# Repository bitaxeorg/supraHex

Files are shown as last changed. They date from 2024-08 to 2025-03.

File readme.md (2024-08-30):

> Closed Source is Antithetical to Bitcoin

# Presenting: The supraHex
supraHex is a follow on to the [bitaxe](https://github.com/skot/bitaxe) that incorporates six BM1368 ASICs from the Antminer S21

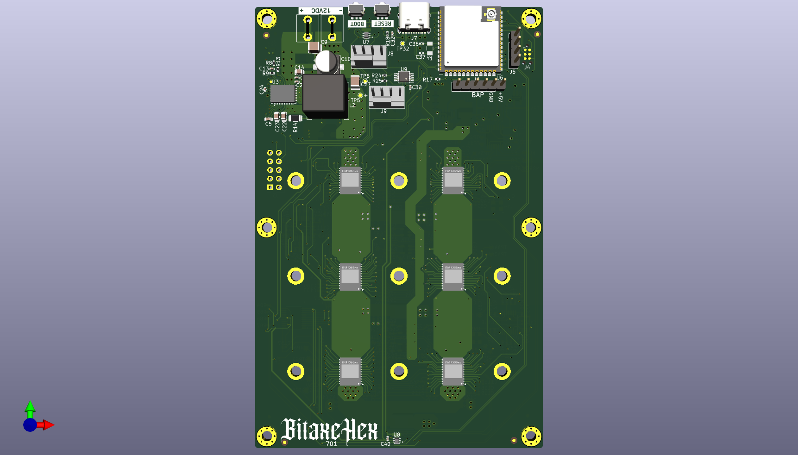
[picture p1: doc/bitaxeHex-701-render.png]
supraHex render


## Goals
- **Standalone**: can mine directly to your pool over WiFi. No External computer needed.
- **Embedded**: low cost, low maintenance, high availability, high reliability, low power.
- **ASIC**: based on the very efficient BM1368 from Bitmain.
- **Versatile**: solo/pool mining, autotune power/heat/efficiency.
- **Open Source**: All design files are provided.

## Features
- **ESP32-S3-WROOM-1** wifi microcontroller on board
- **TI TPS546D24ARVFR** buck regulator steps down the 12V input to power the chain of BM1368
- **TMP1075** measures inlet and outlet PCB temperature.
- **Microchip EMC2302** Controls dual fans
- Header for optional status LCD
- BAP (Bitaxe Accesory Port)
- ASIC Chip temperature directly from the ASIC's

## BM1368
- The BM1368 is a undocumented SHA256 mining ASIC from Bitmain. It's mostly used in the Antminer S21
- Bitmain claims the BM1368 has 17.5 W/TH efficiency
- The BM1368 is available (new) for around $20~29 each.

## Current Status
- v701 hardware is working! Hash rate is fluctuating between 4 TH/s and 4.2 TH/s.
- Power draw is around 75W @12V.
- ESP32 miner firmware will configure the power supply to run at the proper voltage.
- This is an _advanced_ build! If you don't have experience building boards, you should probably go build a single ASIC bitaxe first to get the technique down.

## Revision List
- V701 is the current working version of this board.  If you want to build this, pull down this git tag.

## Hardware
- [BM1368 from NBTC](https://www.nbtcminer.com/shop/miner-parts/miner-chip/new-bm1368-bm1368pb-for-antminer-s21-t21-hdyro/). The `PB`Variant seems to work fine.
- [Heatsink](https://www.aliexpress.us/item/3256805608902122.html) 90mm long variant. This will need to have threaded M3 mounting holes added. See the KiCad board file for the pattern
- [Fans](https://www.amazon.com/Noctua-NF-A8-PWM-Premium-Quiet/dp/B00NEMG62M) At least one 80x80mm 12V 4-pin fan. Like the Noctua NF-A8 PWM. Possibly two.
- [Enclosure](https://www.aliexpress.us/item/3256806064761702.html) (several sellers) 130mm long variant. The supraHex needs to be run inside an enclosure to force air through the heatsink and effectively cool the BM1368s
- All of the parts on the board are listed in the KiCad BOM

## Software
- [ESP-Miner-Multichip](https://github.com/bitaxeorg/esp-miner-multichip) is still being updated to support multiple ASICs

## Power Supply Requirements
- supraHex takes 12V DC input via screw terminals. Power supply should be capable of 100W
  - This [120W Brick](https://www.amazon.com/gp/product/B07PWZQ33N) technically works, but gets a little warmer than it should. You'll need to change the end.
  - 12V 15A 110V AliExpress [Bare PSU](https://www.aliexpress.us/item/3256805439916551.html)

## Building
- Check out [building.md](building.md) for PCB ordering tips
- Check out [assembly.md](assembly.md) for assembly tips

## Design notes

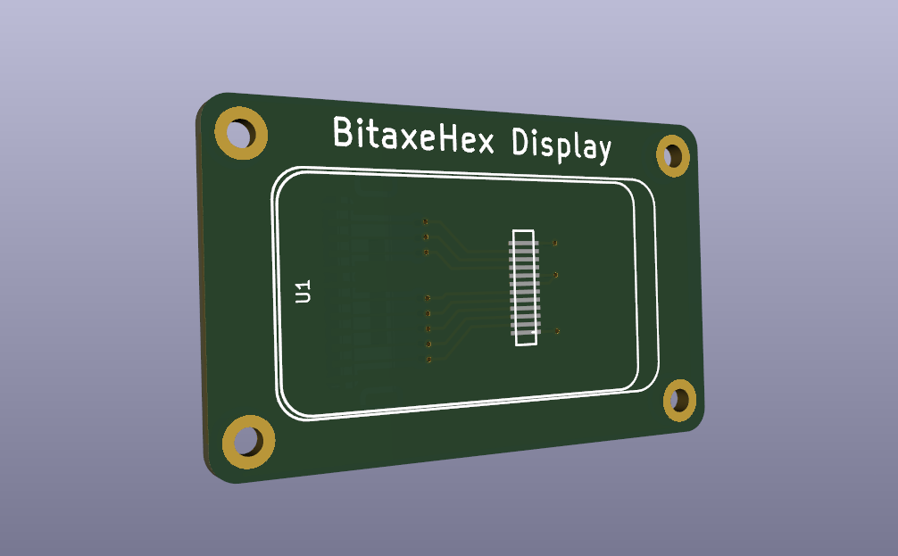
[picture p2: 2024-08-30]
hex-display/doc/display-board-render-front.png

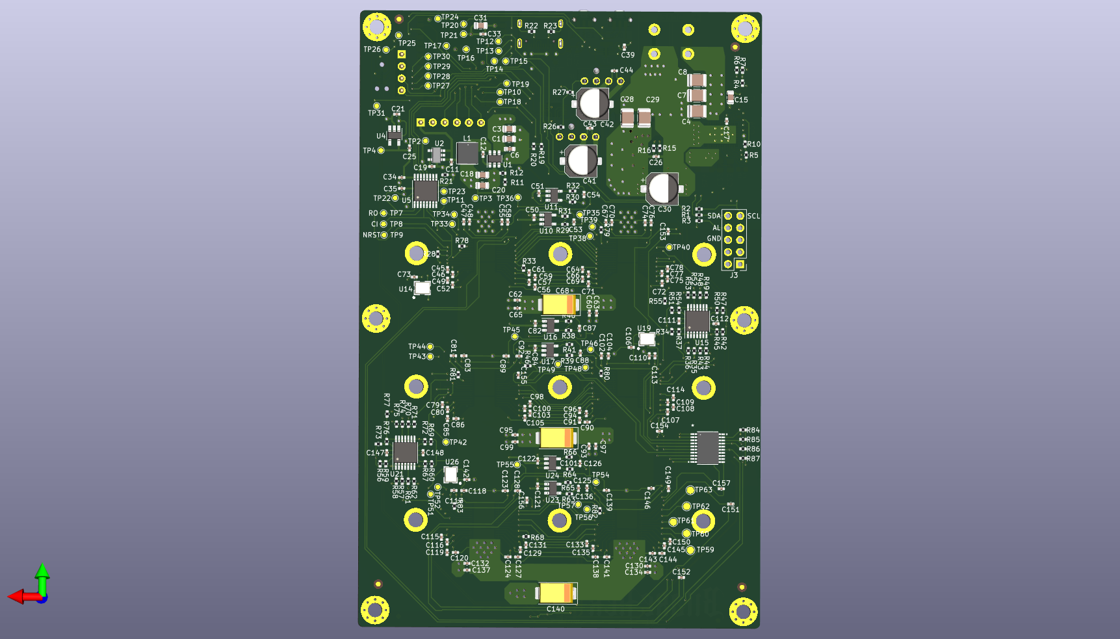
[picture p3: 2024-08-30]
doc/bitaxeHex-701-render-back.png

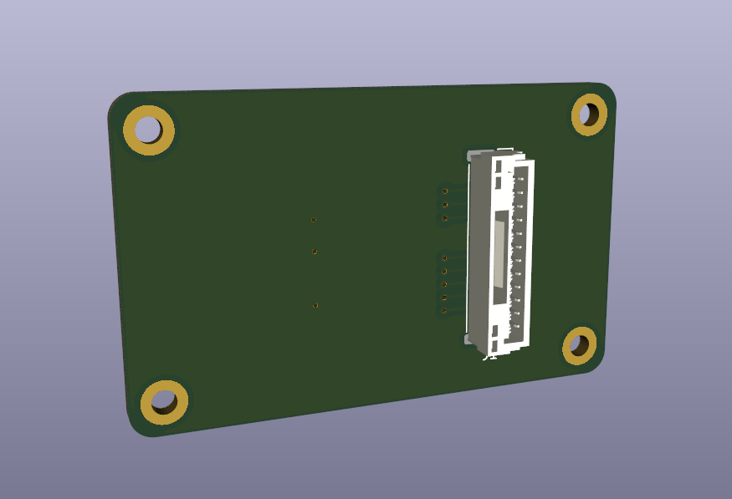
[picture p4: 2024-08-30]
hex-display/doc/display-board-render-back.png

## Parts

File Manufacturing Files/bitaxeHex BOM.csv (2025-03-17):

Reference | Value | Footprint | Qty | DK | PARTNO
C1, C3, C18, C20, C31 | 10uF | Capacitor_SMD:C_0805_2012Metric | 5 | 490-18664-1-ND | GRM21BR61H106ME43L
C2 | 4.7nF | Capacitor_SMD:C_0402_1005Metric | 1 | 490-1309-1-ND | GRM155R71E472KA01D
C4, C7, C8, C9 | 22uF | Capacitor_SMD:C_1210_3225Metric | 4 | 490-3889-1-ND | GRM32ER61E226KE15L
C5 | 1uF | Capacitor_SMD:C_0603_1608Metric | 1 | 490-1550-1-ND | GRM188R60J105KA01D
C6 | 0.1uF | Capacitor_SMD:C_0603_1608Metric | 1 | 478-KGM15BR71H104KTCT-ND | KGM15BR71H104KT
C10, C30 | 180uF | Capacitor_SMD:CP_Elec_6.3x5.9 | 2 | P16479CT-ND | 16SVPF180M
C11, C19, C21, C25, C32, C45, C46, C47, C48, C49, C52, C53, C54, C55, C56, C57, C58, C59, C61, C63, C64, C65, C66, C67, C69, C70, C71, C72, C74, C75, C76, C77, C78, C79, C80, C81, C83, C85, C86, C87, C88, C89, C90, C91, C92, C94, C96, C97, C98, C99, C100, C102, C103, C104, C105, C107, C108, C109, C110, C112, C113, C114, C115, C116, C117, C118, C119, C120, C123, C124, C125, C126, C127, C128, C129, C131, C133, C134, C135, C136, C137, C138, C139, C141, C143, C144, C145, C146, C148, C149, C150 | 1uF | Capacitor_SMD:C_0402_1005Metric | 91 | 587-5514-1-ND | EMK105BJ105MV-F
C12, C33, C50, C51, C60, C62, C73, C82, C84, C93, C95, C106, C111, C121, C122, C130, C132, C142, C147, C151 | 0.1uF | Capacitor_SMD:C_0402_1005Metric | 20 | 478-KGM05AR71C104KHCT-ND | KGM05AR71C104KH
C13 | 100nF | Capacitor_SMD:C_0402_1005Metric | 1 | 490-6321-1-ND | GRM155R71A104KA01D
C14, C15 | 1uF | Capacitor_SMD:C_0805_2012Metric | 2 | 587-1291-1-ND | TMK212BJ105KG-T
C16, C26 | 2.2nF | Capacitor_SMD:C_0402_1005Metric | 2 | 490-8257-1-ND | GRM155R61H222KA01D
C17 | 4.7uF | Capacitor_SMD:C_0402_1005Metric | 1 | 490-14306-1-ND | GRM155R61A475MEAAD
C22 | 1nF | Capacitor_SMD:C_0805_2012Metric | 1 | 311-1127-1-ND | CC0805KRX7R9BB102
C23 | 100nF | Capacitor_SMD:C_0805_2012Metric | 1 | 478-KGM21NR71E104KTCT-ND | KGM21NR71E104KT
C24 | 100pF | Capacitor_SMD:C_0402_1005Metric | 1 | 732-7431-1-ND | 885012005013
C27, C28, C29 | 47uF | Capacitor_SMD:C_1210_3225Metric | 3 | 490-6539-1-ND | GRM32ER61C476KE15L
C34, C35, C38, C39, C40, C43, C44 | 311-3342-1-ND | Capacitor_SMD:C_0402_1005Metric | 7 | 478-KGM05AR71C104KHCT-ND | KGM05AR71C104KH
C41, C42 | 220uF | Capacitor_SMD:CP_Elec_6.3x7.7 | 2 | 732-8422-1-ND | 865080345012
C68, C101, C140 | 330uF | Capacitor_Tantalum_SMD:CP_EIA-7343-31_Kemet-D_Pad2.25x2.55mm_HandSolder | 3 | 718-1028-1-ND | 293D337X9010E2TE3
C152, C153, C154, C155, C156, C157 | 2.2nF | Capacitor_SMD:C_0402_1005Metric | 6 | 311-1037-2-ND | CC0402KRX7R9BB222
D1 | 824045812 | bitaxe:824045812 | 1 | 732-824045812CT-ND | 824045812
J1, J2 | Screw Terminal | bitaxe:7771-screw-terminal | 2 | 36-7771-ND | 36-7771
J3 | Conn_02x05_Odd_Even | Connector_PinHeader_2.54mm:PinHeader_2x05_P2.54mm_Vertical | 1
J6 | Conn_01x06 | Connector_PinHeader_2.54mm:PinHeader_1x06_P2.54mm_Vertical | 1
J7 | USB_C_Receptacle_USB2.0 | Connector_USB:USB_C_Receptacle_GCT_USB4105-xx-A_16P_TopMnt_Horizontal | 1 | 2073-USB4105-GF-ACT-ND | USB4105-GF-A
J8, J9 | Conn_01x04 | bitaxe:470531000 | 2 | WM4330-ND | 0470531000
L1 | 8.2 uH | bitaxe:74438357082 | 1 | 732-11745-1-ND | 78438357082
L2 | 680nH | Inductor_SMD:L_Coilcraft_XAL1010-XXX | 1 | 2457-XAL1010-681MED-ND | XAL1010-681MED
R1, R2, R3 | 0R | Resistor_SMD:R_0402_1005Metric | 3 | 311-0.0JRCT-ND | RC0402JR-070RL
R4, R5 | 17.8K | Resistor_SMD:R_0402_1005Metric | 2 | RMCF0402FT17K8CT-ND | RMCF0402FT17K8
R6 | 10k | Resistor_SMD:R_0402_1005Metric | 1 | RMCF0402FT10K0CT-ND | RMCF0402FT10K0
R7 | 31.6K | Resistor_SMD:R_0402_1005Metric | 1 | YAG3115CT-ND | RC0402FR-0731K6L
R8 | 12.7K | Resistor_SMD:R_0402_1005Metric | 1 | YAG2964CT-ND | RC0402FR-0712K7L
R9, R16 | 1.37K | Resistor_SMD:R_0402_1005Metric | 2 | YAG3035CT-ND | RC0402FR-071K37L
R10 | 26.1K | Resistor_SMD:R_0402_1005Metric | 1 | 311-26.1KLRCT-ND | RC0402FR-0726K1L
R11, R29, R30, R31, R38, R39, R41, R63, R64, R65 | 115k | Resistor_SMD:R_0402_1005Metric | 10 | YAG2956CT-ND | RC0402FR-07115KL
R12, R20 | 22.1k | Resistor_SMD:R_0402_1005Metric | 2 | 311-22.1KLRCT-ND | RC0402FR-0722K1L
R13 | 10R | Resistor_SMD:R_0402_1005Metric | 1 | 311-10.0LRCT-ND | RC0402FR-0710RL
R14 | 1R | Resistor_SMD:R_1206_3216Metric | 1 | CSR1206FT1R00CT-ND | CSR1206FT1R00
R15 | 49.9R | Resistor_SMD:R_0402_1005Metric | 1 | 311-49.9LRCT-ND | RC0402FR-0749R9L
R17, R18, R26, R27, R28, R35, R36, R43, R44, R48, R49, R52, R53, R57, R58, R61, R62, R70, R71, R74, R75 | 10k | Resistor_SMD:R_0402_1005Metric | 21 | 311-10KJRCT-ND | RC0402JR-0710KL
R19 | 7.87k | Resistor_SMD:R_0402_1005Metric | 1 | 311-7.87KLRCT-ND | RC0402FR-077K87L
R21 | 20k | Resistor_SMD:R_0402_1005Metric | 1 | 311-20.0KLRCT-ND | RC0402FR-0720KL
R22, R23 | 5.1k | Resistor_SMD:R_0402_1005Metric | 2 | 13-RC0402FR-135K1LCT-ND | RC0402FR-135K1L
R24, R25 | 5.6k | Resistor_SMD:R_0402_1005Metric | 2 | 13-RC0402FR-135K6LCT-ND | RC0402FR-135K6L
R32, R40, R66 | 402k | Resistor_SMD:R_0402_1005Metric | 3 | YAG3151CT-ND | RC0402FR-07402KL
R33, R46, R68 | 2k | Resistor_SMD:R_0402_1005Metric | 3 | YAG2303CT-ND | RT0402BRD072KL
R34, R37, R42, R45, R47, R50, R51, R54, R55, R56, R59, R60, R67, R69, R72, R73, R76, R77, R78, R79, R80, R81, R82, R83 | 1k | Resistor_SMD:R_0402_1005Metric | 24 | 311-1.00KLRCT-ND | RC0402FR-071KL
R84, R85, R86, R87 | 4.7k | Resistor_SMD:R_0402_1005Metric | 4 | YAG1446TR-ND | RT0402BRD074K7L
SW1, SW2 | SWITCH-SPST | bitaxe:TL3340-switch | 2 | EG4627CT-ND | TL3340AF160QG
U1 | LMR54410 | Package_TO_SOT_SMD:SOT-23-6 | 1 | 296-LMR54410DBVRCT-ND | LMR54410FDBVR
U2 | RT9080-33GJ5 | bitaxe:RT9080-33GJ5 | 1 | 1028-1509-1-ND | RT9080-33GJ5
U3 | TPS546D24ARVFR | bitaxe:LQFN40-CLIP | 1 | 296-TPS546D24ARVFRCT-ND | TPS546D24ARVFR
U4 | MIC5504-MS | Package_TO_SOT_SMD:SOT-23-5_HandSoldering | 1 | 576-4879-1-ND | MIC5504-1.8YM5-TR
U5 | SN74AVC4T774 | Package_SO:TSSOP-16_4.4x5mm_P0.65mm | 1 | 296-24739-1-ND | SN74AVC4T774PWR
U6 | ESP32-S3-WROOM-1 | bitaxe:ESP32-S3-WROOM-1U | 1 | 1965-ESP32-S3-WROOM-1U-N16R8CT-ND | ESP32-S3-WROOM-1U-N16R8
U7, U8 | TMP1075 | bitaxe:SOT5X3-6_DRL_TEX | 2 | 296-TMP1075NDRLRCT-ND | TMP1075NDRLR
U9 | EMC2302 | Package_SO:MSOP-10_3x3mm_P0.5mm | 1 | EMC2302-2-AIZL-CT-ND | EMC2302-2-AIZL-TR
U10, U11, U16, U17, U23, U24 | AP7331 | Package_TO_SOT_SMD:TSOT-23-5 | 6 | AP7331-WG-7DICT-ND | AP7331-WG-7
U12, U25, U27, U28 | BM1368_mode1 | bitaxe:BM1368 | 4
U13, U18 | BM1368_mode0 | bitaxe:BM1368 | 2
U14, U19, U26 | 25MHz | bitaxe:O 25,0-JO32-B-1V3-1-T1-LF | 3 | 1908-O250-JO32-B-1V3-1-T1-LFCT-ND | O 25,0-JO32-B-1V3-1-T1-LF
U15, U21 | TLV3544 | Package_SO:TSSOP-14_4.4x5mm_P0.65mm | 2 | 296-45352-1-ND | TLV3544IPWR
U20 | ~ | bitaxe:MAX6689UP9A+ | 1 | MAX6689UP9A+-ND | MAX6689UP9A+

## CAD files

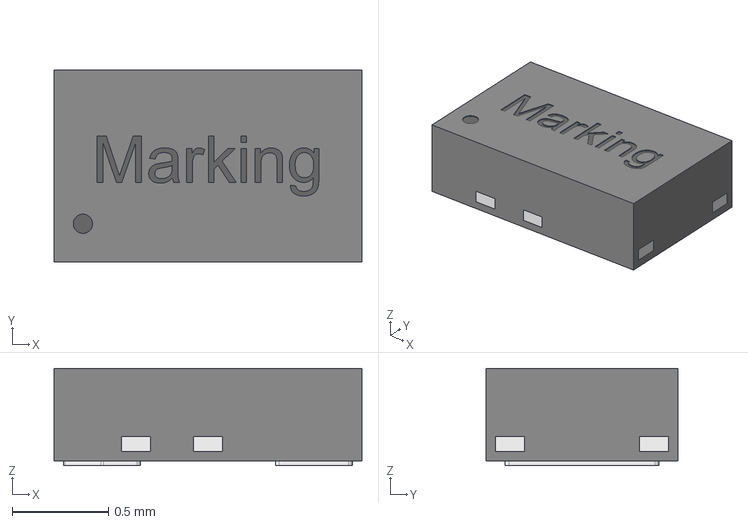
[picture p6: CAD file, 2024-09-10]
3d/Download_STP_WE-TVS-DFN1610-2L_rev1.stp
1.60 x 1.00 x 0.505 mm
pins x 7
housing

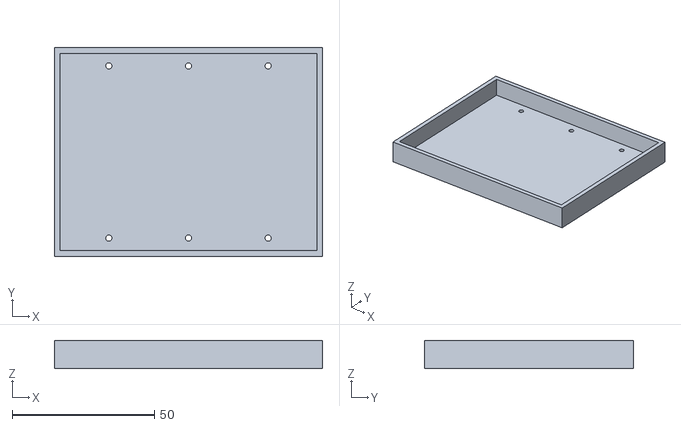
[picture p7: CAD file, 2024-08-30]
3d/heatsink-drill-guide.stl
94.2 x 73.3 x 10.0

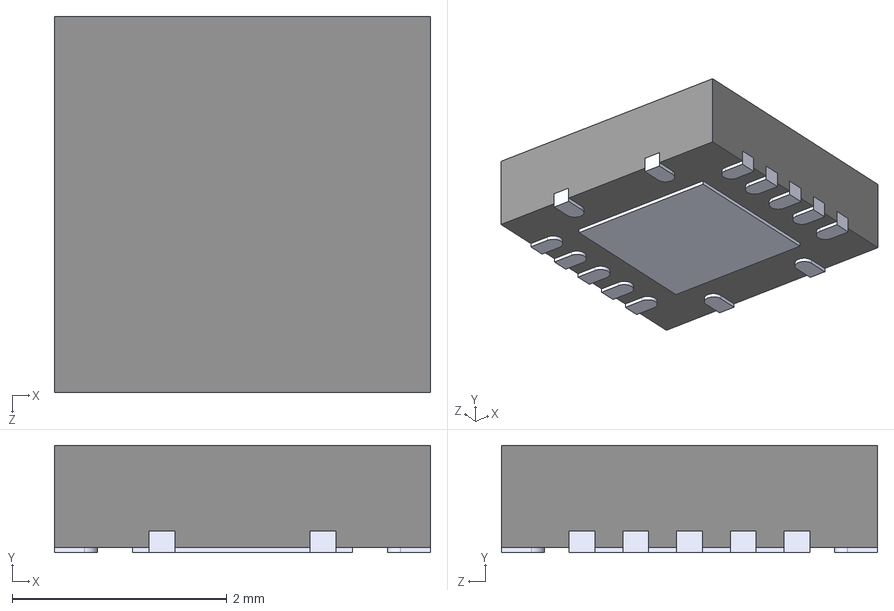
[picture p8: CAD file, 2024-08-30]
3d/TXB0104RGYR.STEP
3.50 x 1.00 x 3.50 mm

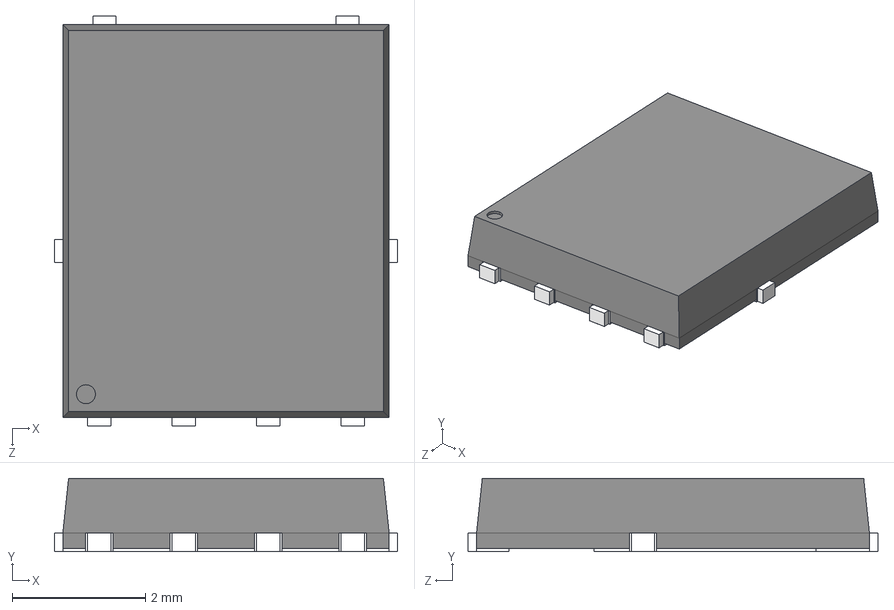
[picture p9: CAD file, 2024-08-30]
3d/NTMFS5C673NLT1G.STEP
5.15 x 1.10 x 6.15 mm

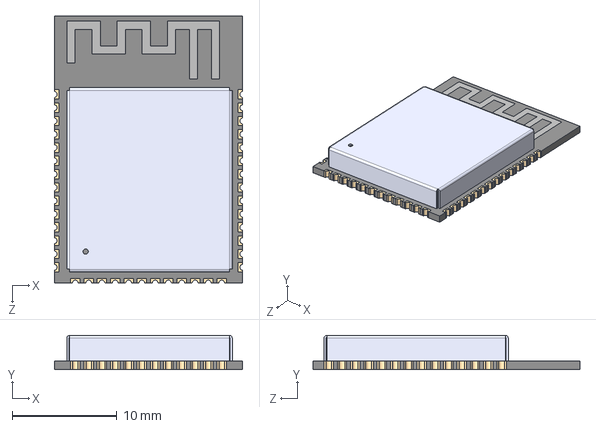
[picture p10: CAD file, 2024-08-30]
3d/ESP32-S3-WROOM-1-N8R2--3DModel-STEP-56544.STEP
18.0 x 3.25 x 25.5 mm

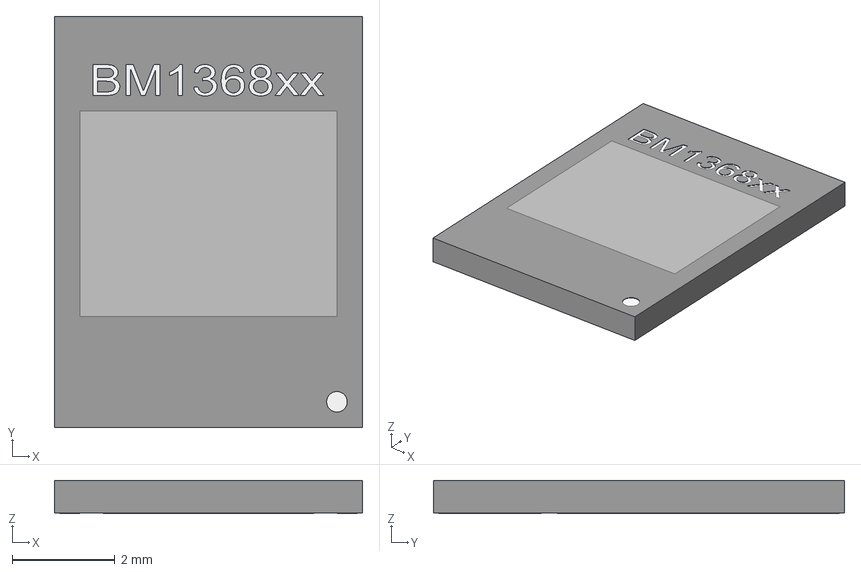
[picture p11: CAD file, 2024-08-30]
3d/BM1368xx.stp
6.00 x 8.00 x 0.65 mm

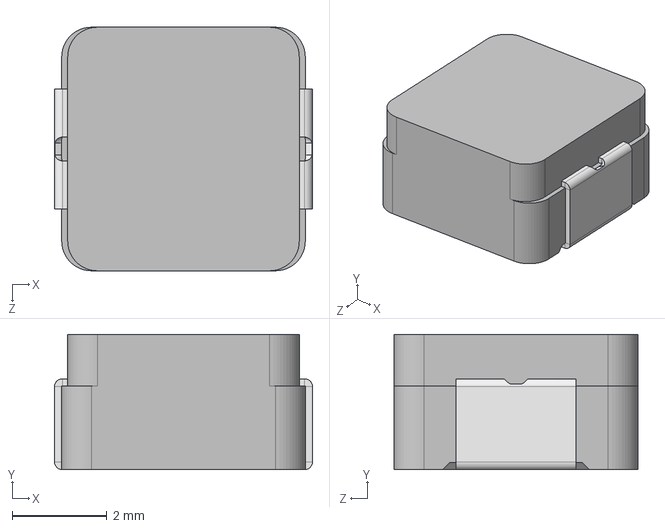
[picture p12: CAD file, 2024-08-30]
3d/IHLP2020CZ.step
5.45 x 2.86 x 5.15 mm

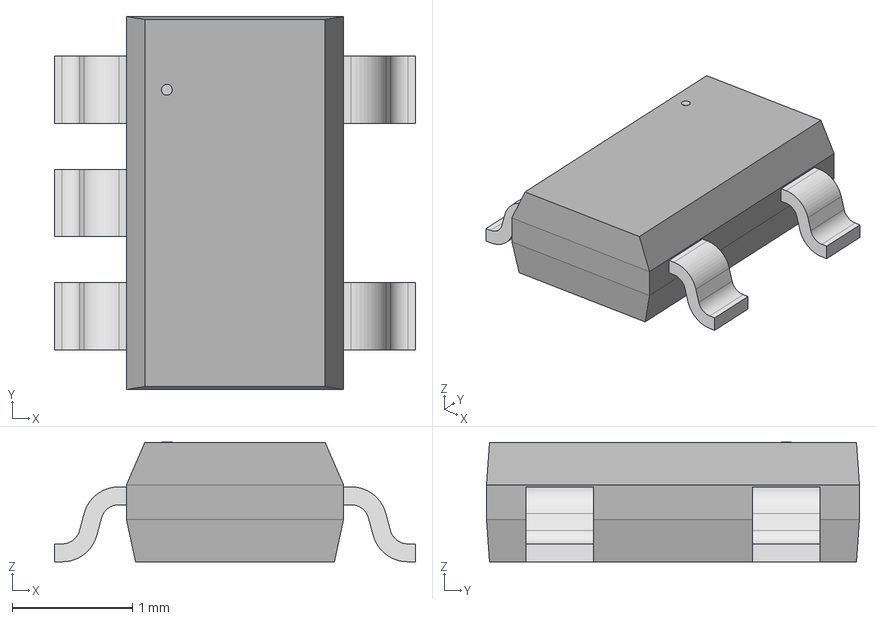
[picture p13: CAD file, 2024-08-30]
3d/TSOT-23-5_RIT.step
3.00 x 3.10 x 0.993 mm

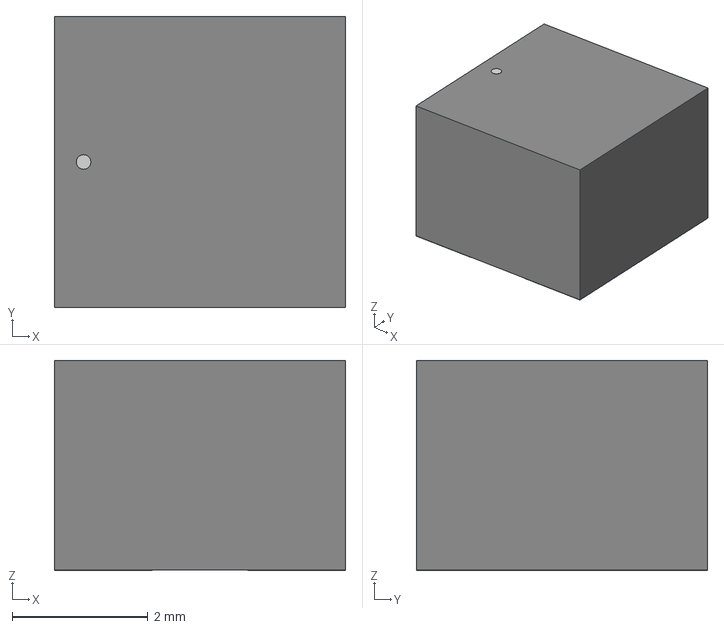
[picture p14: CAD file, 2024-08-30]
3d/IND_4030-WE-MAPI_WRE.step
4.29 x 4.29 x 3.10 mm

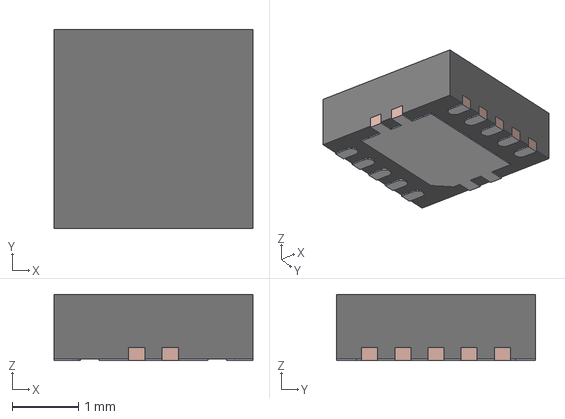
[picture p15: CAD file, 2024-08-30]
3d/DRC0010J.stp
3.00 x 3.00 x 1.00 mm
BODY-SON
FRAME-DRC0010J

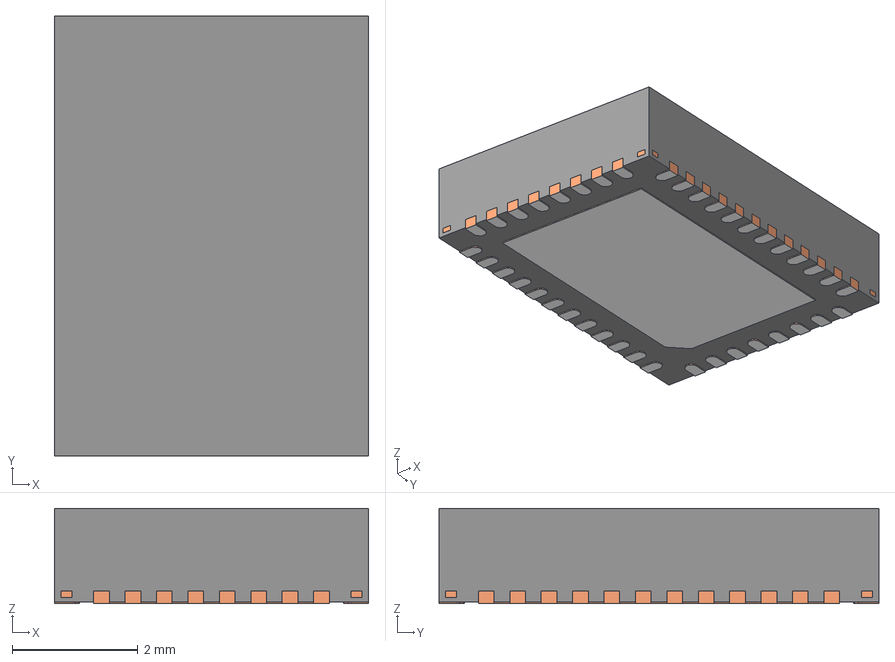
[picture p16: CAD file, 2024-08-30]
3d/RVF0040A.stp
5.00 x 7.00 x 1.52 mm
BODY-QFN
FRAME-RVF0040A
PIN1-ID

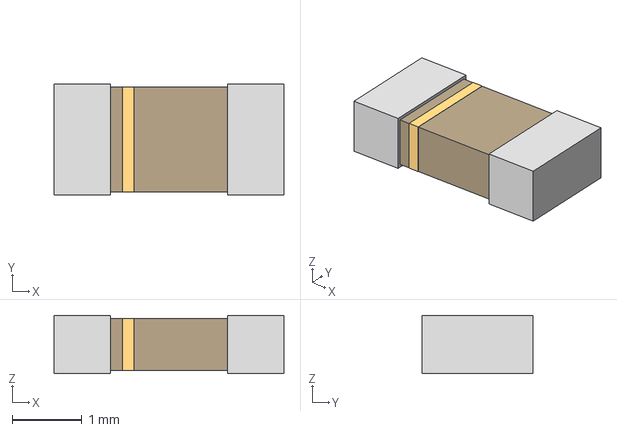
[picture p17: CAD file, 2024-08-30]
3d/XTAL_SC32S-7PF20PPM_EPS.step
3.30 x 1.60 x 0.838 mm

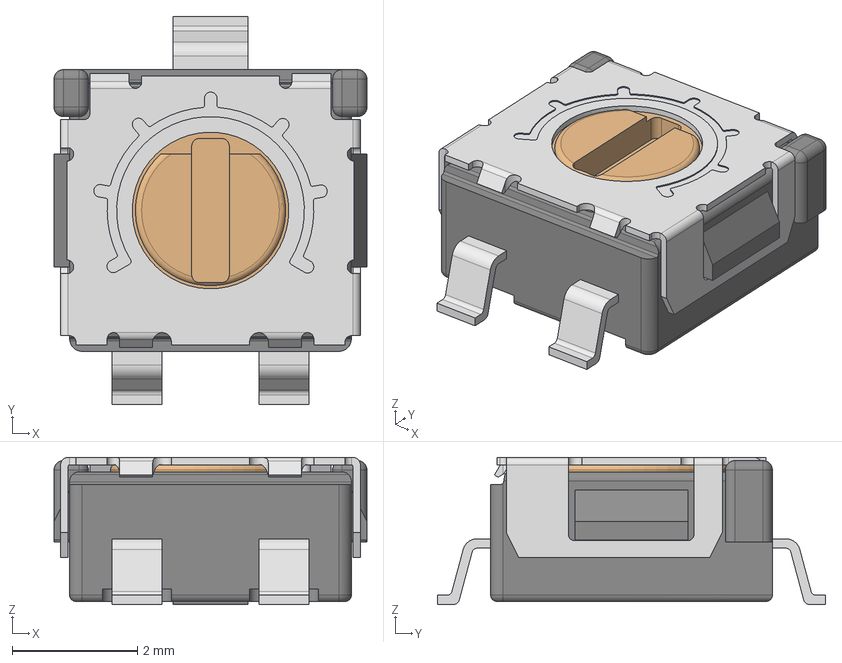
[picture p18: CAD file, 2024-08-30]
3d/ST-4ETB2k_(202).stp
5.00 x 6.20 x 2.35 mm
ST-4EB_terminal_2
ST-4EB_terminal
ST-4EB_terminal_1
ST-4-dial2
ST-4EB10X(100)_body

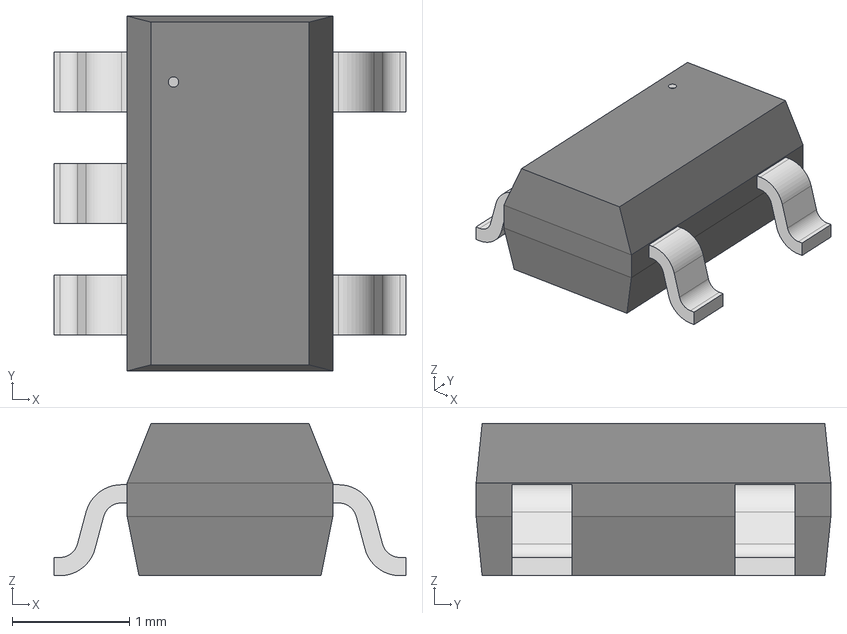
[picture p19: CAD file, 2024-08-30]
3d/SOT-23-5_M5_MCH.step
3.00 x 3.02 x 1.30 mm

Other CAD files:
3d/DQH0008A.stp
3d/c-63862-1-r-3d.stp
3d/2R5TPE220MAFB.step
3d/TL3340AF160QG.step
3d/heatsink.scad
3d/21-0066J_20_MXM.step
3d/21-0164B_L622-1_MXM.step
3d/3225-oscillator.step
3d/470531000.stp
3d/74437358010.stp
3d/7770-ScrewTerminal.step
3d/CSD17577Q5A.stp
3d/CX3225SB16000H0FLJCC.STEP
3d/Cree_PLCC6.stp
3d/DQG0008A.stp
3d/DRL0006A.stp
3d/EVQ-9P701P.stp
3d/FP1006V2-R.STEP
3d/FTSH-105-01-F-DV-K.stp
3d/PLCC6_LED_3_5X3_4X2_8_CRW.step
3d/RUM0016A.stp
3d/SMV_z90.stp
3d/SN74AXC1T45DBVR.STEP
3d/XRCGB27M120F3M10R0_MUR.step
3d/bm1366.STP
3d/heatsink.step

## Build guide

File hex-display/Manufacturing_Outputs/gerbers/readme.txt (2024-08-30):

BitaxeHex Display gerber files

2 copper layers
silkscreen on top only

hex-display-Edge_Cuts.gbr      -Board outline
hex-display-F_Cu.gbr           -Top copper
hex-display-B_Cu.gbr           -Bottom copper
hex-display-F_Mask.gbr         -Top solder mask
hex-display-B_Mask.gbr         -Bottom solder mask
hex-display-F_Silkscreen.gbr   -Top silkscreen
hex-display-PTH.drl            -drill plated-through holes

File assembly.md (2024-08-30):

- Get a convection toaster oven. Nothing fancy, it just has a fan inside for more even heating. Never use this oven for food.
  - [BLACK+DECKER TO3250XSB 8-Slice Extra Wide Convection Countertop Toaster Oven, Includes Bake Pan, Broil Rack & Toasting Rack, Stainless Steel/Black](https://www.amazon.com/BLACK-DECKER-TO3250XSB-Convection-Countertop/dp/B00LU2I428)
- Get a thermocouple thermometer. Make sure the probe and probe jacket can go to ~300C
  - [Digital Thermocouple Temperature Thermometer, PEAKMETER PM6501 K Type LCD Thermometer Testing Tool Celsius and Fahrenheit](https://www.amazon.com/Thermocouple-Temperature-Thermometer-PEAKMETER-Fahrenheit/dp/B08L11MMFM)
- Use Sn63/Pb37 no-clean, leaded, solder paste. Keep it in the refrigerator so it's nice and cold before you stencil it. (obvs don't get it near your food). Wash your hands well after.
  - [Chip Quik SMD291AX50T3 Solder Paste in jar 50g (T3) Sn63/Pb37 no clean](https://www.amazon.com/gp/product/B07BH5LP5G)
- Take your time to get the paste stenciled right. Don't be afraid to wipe it off with IPA and try again. The paste stencils better when it's cold.
- Use tweezers to put all of the parts on the pasted board. I like the curved Aven Technik 7-SA Tweezers. I have also been known to wear a dorky magnifier headset.
  - [Aven 18072ARS 7-SA Style Artis Tweezer, Black with Yellow Print](https://www.amazon.com/Aven-18072ARS-Style-Tweezer-Yellow/dp/B01D4R1OXW)
  - [Headband Magnifier Hands Free Jeweler Loupe Head Mount Magnifying Headset Visor Double Optical Glass 4 Replaceable Lenses for Reading,Repair(1.5X,2.0X,2.5X,3.5X)](https://www.amazon.com/Headband-Magnifier-Jeweler-Magnifying-Replaceable/dp/B08RYVH7DL)
- Put the board(s) in the toaster oven. I usually put them right on the wire rack, which is in the metal tray.
- Put the thermocouple inside the toaster oven. Close the door on the thermocouple wire so that it holds the end right above the PCB, inside the oven.
- Turn the oven on convection bake, medium setting. The convection fan in the toaster oven helps keep the temperature even through out the inside of the oven.
- Once the temp (as read off the thermocouple thermometer) gets to 140C, turn down the oven heat and try and keep it at 140-150C for 2 minutes. Open the door a little if it's getting to hot. This is the "Soak" phase
- After two minutes, turn the heat to high
- Once the temp reaches 200C start a timer for 30 seconds. Keep the temp between 200 and 220C for this phase. Usually you don't need to do anything. This is the "Reflow" phase. You should see all of the paste melt.
- After 30 seconds, turn off the toaster oven. open the door.
- Let the boards cool for a bit in the oven with the door open.
- Once cool to touch, inspect the boards with a microscope for dry pads and/or bridges. Depending on how well you did with stenciling there may be a few, especially on QFP packages. QFNs sometimes too. Fix these up with paste flux, solder braid and your soldering iron.
- If you have parts on both sides of the board, it's fine to just repeat the steps on the second side. The surface tension of the solder almost always keeps the parts from falling off while they are getting reflowed upside down. When you reflow the second side, make a little stand out of metal to keep the bottom side parts off the wire rack in the toaster oven.

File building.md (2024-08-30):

# Building PCBs

In order to get PCBs made, you usually need to provide them with the following files;

- Gerbers
- Drill Files

Additionally if you want to have a shop assemble the boards for you, you’ll also need to provide;

- Bill of Materials (BOM)
- Centroid file (XY)

### Generating Gerbers and Drill Files

Gerbers are a set of files in a standard format that allow a PCB manufacturer to build the PCB. Usually there is one gerber file for each layer of a PCB. A Gerber file can represent a wide variety of different layer types;

- Copper layer
- Silkscreen Layer
- Soldermask layer
- Board outline
- Drills (Okay, this is actually not a gerber, but your PCB house will definitely need it)

Any* PCB CAD software will allow you to generate gerbers. We use [KiCad](https://www.kicad.org) because it is open source, free, and *awesome*. Here is how to generate gerbers in KiCad v6;

1. Open up the design in KiCad and switch to the PCB board editor view (ie not the schematic). Some people call this pcbnew.
2. Choose File → Fabrication Outputs → Gerbers (.gbr)…
3. Pick the right options for what your PCB board house expects. Here is what I use;

Gerber Plot Window

Make sure you have these “Include Layers” checked;

- **F.Cu** → Front copper
- **In1.Cu** → Inner layer 1 Copper
- **In2.Cu** → Inner layer 2 Copper
- **B.Cu** → Back copper
- **F.Paste** → Front Paste. Note: this is used to make a solder paste stencil. This is optional. Many PCB houses will let you order stencils as a separate step. use these gerbers for ordering a stencil
- **B.Paste** → Back paste. see note above
- **F.Silkscreen** → Front Silkscreen. sometimes this is called the Legend
- **B.Silkscreen** → Back Silkscreen. sometimes this is called the Legend of Zelda
- **F.Mask** → Front soldermask
- **B.Mask** → Back soldermask
- **Edge.Cuts** → The board outline. This defines the shape the PCB is cut to.

1. Next you’ll want to generate the drill files. Click that button in the lower right corner of the “Plot” screen from above.
2. Generate the drill files according to your PCB house specs. Here are the options I use;

Drill Files Window

That’s it! Take all of those generated files and give them to your PCB house. If you’re ordering stencils (which you should!), pull out `-F_Paste.gbr` and `-B_Paste.gbr` and send those to the right place. Paste gerbers are not needed to manufacture a PCB.

### Generating PCBA Manufacturing files

- TBD

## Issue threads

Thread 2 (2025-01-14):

Question about netlist on BM1368 chips

martonymous, 2025-01-14:
I noticed that pin 14 on U12 is assigned to GND. Am I correct to assume that this is a mistake? I can't find any datasheets for this chip, so maybe I am misunderstanding something.

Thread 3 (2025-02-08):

Ambiguous voltage on BM1368 pins 15 and 16

martonymous, 2025-02-08:
From the schematics and the symbol itself, the voltage values for pins 15 and 16 on the BM1368 are ambiguous and could be interpreted as either 1v8 or 1v2. Though according to the resistor values for the LDO, the supplied voltage is 1v8, which is less ambiguous. I am guessing that is correct.

On a related note, I can't find the datasheet for the ASIC and the symbol itself indicates 1v2 should be used. Do you know why one value should be chosen instead of another?

HornSuperSet, 2025-02-12:
I have noticed that the resistor value on the BOM is 220k, but on the schematic its 402k for pins 15, 16. maybe finding data sheets for other asic chips might be the solution but is risky.

martonymous, 2025-02-14:
I didn't even notice that, well spotted! So the included BOM would indeed suggest that the voltage is 1.2V. The only somewhat official source I found for this and a few other chips is this [site](https://osmu.wiki/osmu-lab/bm1368/) which also seems to suggest that either works. But again, there is this ambiguous phrasing "1.8V IO voltage (this is normally 1.2V now)". I will try out with 1.2V, see if that works.

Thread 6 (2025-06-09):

DRC Failing

ahmedalalousi, 2025-06-09:
Hi,

DRC fails on stock deigns, with an awful lot of errors, relating to shortened and unconnected nets, amongst the most serious. Report below.

Any ideas?

Thanks.

** Drc report for bitaxeHex.kicad_pcb **
** Created on 2025-06-09T15:54:29+0100 **

** Found 81 DRC violations **
[shorting_items]: Items shorting two nets (nets GND and Net-(U28-VDDIO_08_0))
    Local override; error
    @(111.9010 mm, 93.9740 mm): Track [GND] on F.Cu, length 0.9030 mm
    @(110.9980 mm, 93.9740 mm): Pad 14 [Net-(U28-VDDIO_08_0)] of U28 on F.Cu
[shorting_items]: Items shorting two nets (nets  and /Power/AGND)
    Local override; error
    @(55.1250 mm, 72.0000 mm): Segment [<no net>] on F.Cu
    @(54.9000 mm, 72.0000 mm): Track [/Power/AGND] on F.Cu, length 1.2000 mm
[shorting_items]: Items shorting two nets (nets /1V8 and /ESP32/1V8)
    Local override; error
    @(123.0375 mm, 81.1000 mm): Track [/1V8] on B.Cu, length 0.0884 mm
    @(122.9750 mm, 81.0375 mm): Pad 16 [/ESP32/1V8] of U5 on B.Cu
[shorting_items]: Items shorting two nets (nets /1V8 and /ESP32/1V8)
    Local override; error
    @(125.2200 mm, 81.1000 mm): Track [/1V8] on B.Cu, length 2.1825 mm
    @(122.9750 mm, 81.0375 mm): Pad 16 [/ESP32/1V8] of U5 on B.Cu
[shorting_items]: Items shorting two nets (nets /ESP32/1V8 and /1V8)
    Local override; error
    @(125.2200 mm, 81.1000 mm): Pad 2 [/ESP32/1V8] of C34 on B.Cu
    @(125.2200 mm, 78.8200 mm): Track [/1V8] on B.Cu, length 2.2800 mm
[shorting_items]: Items shorting two nets (nets GND and Net-(U28-VDDIO_08_0))
    Local override; error
    @(112.5500 mm, 90.8800 mm): Track [GND] on B.Cu, length 0.1061 mm
    @(112.6250 mm, 90.8050 mm): Pad 1 [Net-(U28-VDDIO_08_0)] of C47 on B.Cu
[shorting_items]: Items shorting two nets (nets Net-(U28-VDDIO_08_0) and GND)
    Local override; error
    @(112.6250 mm, 90.8050 mm): Pad 1 [Net-(U28-VDDIO_08_0)] of C47 on B.Cu
    @(112.5500 mm, 91.9750 mm): Track [GND] on B.Cu, length 1.0950 mm
[clearance]: Clearance violation (netclass 'Default' clearance 0.2032 mm; actual 0.0900 mm)
    Rule: netclass 'Default'; error
    @(91.0100 mm, 110.6100 mm): Track [/BM1368-2/1V8] on B.Cu, length 0.4384 mm
    @(91.0000 mm, 111.1200 mm): Pad 1 [/BM1368-2/1V2] of R40 on B.Cu
[shorting_items]: Items shorting two nets (nets /BM1368-2/1V8 and /BM1368-2/1V2)
    Local override; error
    @(103.1000 mm, 115.5000 mm): Track [/BM1368-2/1V8] on B.Cu, length 1.5556 mm
    @(101.8000 mm, 114.4000 mm): Pad 1 [/BM1368-2/1V2] of TP45 on B.Cu
[shorting_items]: Items shorting two nets (nets /BM1368-2/1V2 and /BM1368-2/1V8)
    Local override; error
    @(88.2000 mm, 112.1200 mm): Pad 1 [/BM1368-2/1V2] of C87 on B.Cu
    @(87.3800 mm, 112.1200 mm): Track [/BM1368-2/1V8] on B.Cu, length 0.8200 mm
[shorting_items]: Items shorting two nets (nets /BM1368-2/1V2 and /BM1368-2/1V8)
    Local override; error
    @(91.0000 mm, 111.1200 mm): Pad 1 [/BM1368-2/1V2] of R40 on B.Cu
    @(91.0100 mm, 111.2000 mm): Track [/BM1368-2/1V8] on B.Cu, length 0.5900 mm
[shorting_items]: Items shorting two nets (nets /BM1368-2/1V2 and /BM1368-2/1V8)
    Local override; error
    @(101.8000 mm, 114.4000 mm): Pad 1 [/BM1368-2/1V2] of TP45 on B.Cu
    @(102.0000 mm, 114.4000 mm): Track [/BM1368-2/1V8] on B.Cu, length 0.2000 mm
[shorting_items]: Items shorting two nets (nets /BM1368-2/1V2 and /BM1368-2/1V8)
    Local override; error
    @(101.8000 mm, 114.4000 mm): Pad 1 [/BM1368-2/1V2] of TP45 on B.Cu
    @(100.7750 mm, 114.4000 mm): Track [/BM1368-2/1V8] on B.Cu, length 1.0250 mm
[shorting_items]: Items shorting two nets (nets /BM1368-2/1V2 and /BM1368-2/1V8)
    Local override; error
    @(88.2000 mm, 112.1200 mm): Pad 1 [/BM1368-2/1V2] of C87 on B.Cu
    @(88.2000 mm, 111.2000 mm): Track [/BM1368-2/1V8] on B.Cu, length 0.9200 mm
[shorting_items]: Items shorting two nets (nets /BM1368-2/1V2 and /BM1368-2/1V8)
    Local override; error
    @(93.1625 mm, 111.1500 mm): Pad 5 [/BM1368-2/1V2] of U16 on B.Cu
    @(93.1625 mm, 111.1500 mm): Track [/BM1368-2/1V8] on B.Cu, length 2.1025 mm
[clearance]: Clearance violation (netclass 'Default' clearance 0.2032 mm; actual 0.1500 mm)
    Rule: netclass 'Default'; error
    @(92.6625 mm, 140.0500 mm): Pad 5 [/BM1368-3/1V2] of U24 on B.Cu
    @(91.7500 mm, 140.0500 mm): Track [/BM1368-3/1V8] on B.Cu, length 0.4950 mm
[shorting_items]: Items shorting two nets (nets /BM1368-3/1V8 and /BM1368-3/1V2)
    Local override; error
    @(88.0000 mm, 139.6000 mm): Track [/BM1368-3/1V8] on B.Cu, length 0.9200 mm
    @(88.0000 mm, 140.5200 mm): Pad 1 [/BM1368-3/1V2] of C126 on B.Cu
[clearance]: Clearance violation (netclass 'Default' clearance 0.2032 mm; actual 0.0300 mm)
    Rule: netclass 'Default'; error
    @(90.8100 mm, 139.2100 mm): Track [/BM1368-3/1V8] on B.Cu, length 0.4384 mm
    @(90.8000 mm, 139.6600 mm): Pad 1 [/BM1368-3/1V2] of R66 on B.Cu
[shorting_items]: Items shorting two nets (nets /BM1368-3/1V2 and /BM1368-3/1V8)
    Local override; error
    @(92.6625 mm, 140.0500 mm): Pad 5 [/BM1368-3/1V2] of U24 on B.Cu
    @(92.6625 mm, 140.0500 mm): Track [/BM1368-3/1V8] on B.Cu, length 0.9125 mm
[shorting_items]: Items shorting two nets (nets /BM1368-3/1V8 and /BM1368-3/1V2)
    Local override; error
    @(101.2000 mm, 141.3000 mm): Track [/BM1368-3/1V8] on B.Cu, length 1.1000 mm
    @(101.2000 mm, 141.3000 mm): Pad 1 [/BM1368-3/1V2] of TP55 on B.Cu
[shorting_items]: Items shorting two nets (nets /BM1368-3/1V2 and /BM1368-3/1V8)
    Local override; error
    @(88.0000 mm, 140.5200 mm): Pad 1 [/BM1368-3/1V2] of C126 on B.Cu
    @(88.0000 mm, 140.5200 mm): Track [/BM1368-3/1V8] on B.Cu, length 0.8200 mm
[shorting_items]: Items shorting two nets (nets /BM1368-3/1V2 and /BM1368-3/1V8)
    Local override; error
    @(90.8000 mm, 139.6600 mm): Pad 1 [/BM1368-3/1V2] of R66 on B.Cu
    @(90.8100 mm, 139.7000 mm): Track [/BM1368-3/1V8] on B.Cu, length 0.4900 mm
[shorting_items]: Items shorting two nets (nets /BM1368-3/1V2 and /BM1368-3/1V8)
    Local override; error
    @(90.8000 mm, 139.6600 mm): Pad 1 [/BM1368-3/1V2] of R66 on B.Cu
    @(91.4000 mm, 139.7000 mm): Track [/BM1368-3/1V8] on B.Cu, length 0.5900 mm
[clearance]: Clearance violation (netclass 'Default' clearance 0.2032 mm; actual 0.2000 mm)
    Rule: netclass 'Default'; error
    @(95.9000 mm, 67.6750 mm): Pad 1 [/SDA] of U9 on F.Cu
    @(95.9000 mm, 67.1750 mm): Pad 2 [/SCL] of U9 on F.Cu
[clearance]: Clearance violation (netclass 'Default' clearance 0.2032 mm; actual 0.2000 mm)
    Rule: netclass 'Default'; error
    @(95.9000 mm, 67.1750 mm): Pad 2 [/SCL] of U9 on F.Cu
    @(95.9000 mm, 66.6750 mm): Pad 3 [/3V3] of U9 on F.Cu
[clearance]: Clearance violation (netclass 'Default' clearance 0.2032 mm; actual 0.2000 mm)
    Rule: netclass 'Default'; error
    @(95.9000 mm, 66.6750 mm): Pad 3 [/3V3] of U9 on F.Cu
    @(95.9000 mm, 66.1750 mm): Pad 4 [GND] of U9 on F.Cu
[clearance]: Clearance violation (netclass 'Default' clearance 0.2032 mm; actual 0.2000 mm)
    Rule: netclass 'Default'; error
    @(95.9000 mm, 66.1750 mm): Pad 4 [GND] of U9 on F.Cu
    @(95.9000 mm, 65.6750 mm): Pad 5 [/Fan/FAN1_PWM] of U9 on F.Cu
[clearance]: Clearance violation (netclass 'Default' clearance 0.2032 mm; actual 0.2000 mm)
    Rule: netclass 'Default'; error
    @(91.5000 mm, 65.6750 mm): Pad 6 [/Fan/FAN1_TACH] of U9 on F.Cu
    @(91.5000 mm, 66.1750 mm): Pad 7 [/Fan/FAN2_PWM] of U9 on F.Cu
[clearance]: Clearance violation (netclass 'Default' clearance 0.2032 mm; actual 0.2000 mm)
    Rule: netclass 'Default'; error
    @(91.5000 mm, 66.1750 mm): Pad 7 [/Fan/FAN2_PWM] of U9 on F.Cu
    @(91.5000 mm, 66.6750 mm): Pad 8 [/Fan/FAN2_TACH] of U9 on F.Cu
[clearance]: Clearance violation (netclass 'Default' clearance 0.2032 mm; actual 0.2000 mm)
    Rule: netclass 'Default'; error
    @(91.5000 mm, 66.6750 mm): Pad 8 [/Fan/FAN2_TACH] of U9 on F.Cu
    @(91.5000 mm, 67.1750 mm): Pad 9 [unconnected-(U9-CLK-Pad9)] of U9 on F.Cu
[clearance]: Clearance violation (netclass 'Default' clearance 0.2032 mm; actual 0.2000 mm)
    Rule: netclass 'Default'; error
    @(91.5000 mm, 67.1750 mm): Pad 9 [unconnected-(U9-CLK-Pad9)] of U9 on F.Cu
    @(91.5000 mm, 67.6750 mm): Pad 10 [unconnected-(U9-*ALERT-Pad10)] of U9 on F.Cu
[clearance]: Clearance violation (netclass 'Default' clearance 0.2032 mm; actual 0.0000 mm)
    Rule: netclass 'Default'; error
    @(54.9000 mm, 72.0000 mm): Pad 37 [/Power/AGND] of U3 on F.Cu
    @(55.1250 mm, 72.0000 mm): Segment [<no net>] on F.Cu
[clearance]: Clearance violation (netclass 'Default' clearance 0.2032 mm; actual 0.0000 mm)
    Rule: netclass 'Default'; error
    @(56.0000 mm, 71.7500 mm): PTH pad 41 [GND] of U3
    @(55.1250 mm, 72.0000 mm): Segment [<no net>] on F.Cu
[clearance]: Clearance violation (netclass 'Default' clearance 0.2032 mm; actual 0.0000 mm)
    Rule: netclass 'Default'; error
    @(58.4000 mm, 71.7500 mm): Pad 41 [GND] of U3 on F.Cu
    @(55.1250 mm, 72.0000 mm): Segment [<no net>] on F.Cu
[clearance]: Clearance violation (netclass 'Default' clearance 0.2032 mm; actual 0.2000 mm)
    Rule: netclass 'Default'; error
    @(99.8700 mm, 53.4200 mm): Pad A1 [GND] of J7 on F.Cu
    @(99.0700 mm, 53.4200 mm): Pad A4 [Net-(J7-VBUS-PadA4)] of J7 on F.Cu
[clearance]: Clearance violation (netclass 'Default' clearance 0.2032 mm; actual 0.2000 mm)
    Rule: netclass 'Default'; error
    @(99.8700 mm, 53.4200 mm): Pad A1 [GND] of J7 on F.Cu
    @(99.0700 mm, 53.4200 mm): Pad B9 [Net-(J7-VBUS-PadA4)] of J7 on F.Cu
[clearance]: Clearance violation (netclass 'Default' clearance 0.2032 mm; actual 0.2000 mm)
    Rule: netclass 'Default'; error
    @(99.0700 mm, 53.4200 mm): Pad A4 [Net-(J7-VBUS-PadA4)] of J7 on F.Cu
    @(98.4200 mm, 53.3750 mm): Pad B8 [unconnected-(J7-SBU2-PadB8)] of J7 on F.Cu
[clearance]: Clearance violation (netclass 'Default' clearance 0.2032 mm; actual 0.2000 mm)
    Rule: netclass 'Default'; error
    @(99.0700 mm, 53.4200 mm): Pad A4 [Net-(J7-VBUS-PadA4)] of J7 on F.Cu
    @(99.8700 mm, 53.4200 mm): Pad B12 [GND] of J7 on F.Cu
[clearance]: Clearance violation (netclass 'Default' clearance 0.2032 mm; actual 0.2000 mm)
    Rule: netclass 'Default'; error
    @(97.9200 mm, 53.3750 mm): Pad A5 [Net-(J7-CC1)] of J7 on F.Cu
    @(98.4200 mm, 53.3750 mm): Pad B8 [unconnected-(J7-SBU2-PadB8)] of J7 on F.Cu
[clearance]: Clearance violation (netclass 'Default' clearance 0.2032 mm; actual 0.2000 mm)
    Rule: netclass 'Default'; error
    @(97.9200 mm, 53.3750 mm): Pad A5 [Net-(J7-CC1)] of J7 on F.Cu
    @(97.4200 mm, 53.3750 mm): Pad B7 [Net-(U6-GPIO19/U1RTS/ADC2_CH8/CLK_OUT2/USB_D-)] of J7 on F.Cu
[clearance]: Clearance violation (netclass 'Default' clearance 0.2032 mm; actual 0.2000 mm)
    Rule: netclass 'Default'; error
    @(96.9200 mm, 53.3750 mm): Pad A6 [Net-(U6-GPIO20/U1CTS/ADC2_CH9/CLK_OUT1/USB_D+)] of J7 on F.Cu
    @(96.4200 mm, 53.3750 mm): Pad A7 [Net-(U6-GPIO19/U1RTS/ADC2_CH8/CLK_OUT2/USB_D-)] of J7 on F.Cu
[clearance]: Clearance violation (netclass 'Default' clearance 0.2032 mm; actual 0.2000 mm)
    Rule: netclass 'Default'; error
    @(96.9200 mm, 53.3750 mm): Pad A6 [Net-(U6-GPIO20/U1CTS/ADC2_CH9/CLK_OUT1/USB_D+)] of J7 on F.Cu
    @(97.4200 mm, 53.3750 mm): Pad B7 [Net-(U6-GPIO19/U1RTS/ADC2_CH8/CLK_OUT2/USB_D-)] of J7 on F.Cu
[clearance]: Clearance violation (netclass 'Default' clearance 0.2032 mm; actual 0.2000 mm)
    Rule: netclass 'Default'; error
    @(96.4200 mm, 53.3750 mm): Pad A7 [Net-(U6-GPIO19/U1RTS/ADC2_CH8/CLK_OUT2/USB_D-)] of J7 on F.Cu
    @(95.9200 mm, 53.3750 mm): Pad B6 [Net-(U6-GPIO20/U1CTS/ADC2_CH9/CLK_OUT1/USB_D+)] of J7 on F.Cu
[clearance]: Clearance violation (netclass 'Default' clearance 0.2032 mm; actual 0.2000 mm)
    Rule: netclass 'Default'; error
    @(95.4200 mm, 53.3750 mm): Pad A8 [unconnected-(J7-SBU1-PadA8)] of J7 on F.Cu
    @(95.9200 mm, 53.3750 mm): Pad B6 [Net-(U6-GPIO20/U1CTS/ADC2_CH9/CLK_OUT1/USB_D+)] of J7 on F.Cu
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

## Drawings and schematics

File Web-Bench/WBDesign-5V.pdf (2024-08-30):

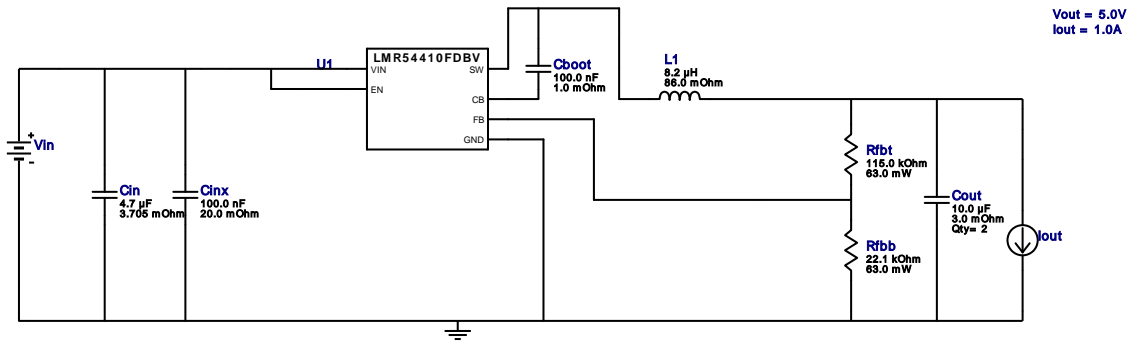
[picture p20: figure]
LM R5 4 4 1 0 FDBV; GND; VIN; Cout 10.0 µF 3.0 m Ohm Qty= 2; Cinx 100.0 nF 20.0 m Ohm; L1 8.2 µH 86.0 m Ohm; Rfbb 22.1 kOhm 63.0 m W; Rfbt 115.0 kOhm 63.0 m W; Vout = 5.0V Iout = 1.0A; Cboot 100.0 nF 1.0 m Ohm; Cin 4.7 µF 3.705 m Ohm; Vin; Iout

Copyright © 2023, Texas Instruments Incorporated | 1 | ti.com/webench

WEBENCH®
Design Report LMR54410FDBVR : LMR54410FDBVR 11V-16V to 5.00V @ 1A December 9, 2023 01:14:49 GMT-06:00

## WEBENCH ® Design Report

Design : 11 LMR54410FDBVR
LMR54410FDBVR 11V-16V to 5.00V @ 1A

VinMin = 11.0V
VinMax = 16.0V
Vout = 5.0V
Iout = 1.0A

Device = LMR54410FDBVR
Topology = Buck
Created = 2023-12-08 23:25:29.060 BOM Cost = $1.70
BOM Count = 9
Total Pd = 0.55W

## Electrical BOM

Name | Manufacturer | Part Number | Properties | Qty Price | Footprint
Cboot | MuRata | GRM155R71C104KA88D (http://search.murata.co.jp/Ceramy/PnsearchViewAction.do) Series= X7R | Cap= 100.0 nF ESR= 1.0 mOhm VDC= 16.0 V IRMS= 0.0 A
1 | $0.01
| | | | | 0402 3 mm²
Cin | MuRata | GRM31CR71E475KA88L (http://psearch.en.murata.com/capacitor/result/smd/?status%3Dall%26pid%3DGRM31CR71E475KA88L) Series= X7R

Cap= 4.7 uF
ESR= 3.705 mOhm
VDC= 25.0 V
IRMS= 2.8649 A

1 $0.09
1206_190 11 mm²
Cinx | MuRata | GRM188R71H104KA93D Series= X7R

Cap= 100.0 nF
ESR= 20.0 mOhm
VDC= 50.0 V
IRMS= 3.8 A

1 $0.02
0603 5 mm²
Cout | Kemet | C0805C106K8PACTU (http://capacitoredge.kemet.com/capedge2/DataSheet/Datasheet%2DC0805C106K8PACTU.pdf?pn%3DC0805C106K8PACTU) Series= X5R

Cap= 10.0 uF
ESR= 3.0 mOhm
VDC= 10.0 V
IRMS= 11.43 A

2 $0.03
0805 7 mm²
L1 | Wurth Elektronik | 74438357082 (http://katalog.we%2Donline.de/pbs/datasheet/74438357082.pdf) | L= 8.2 µH 86.0 mOhm | 1 | $1.22
WE-MAPI_4030 26 mm²
Rfbb | Vishay-Dale | CRCW040222K1FKED (http://www.vishay.com/docs/20035/dcrcwe3.pdf) Series= CRCW..e3 | Res= 22.1 kOhm Power= 63.0 mW Tolerance= 1.0% | 1 | $0.01
0402 3 mm²
Rfbt | Vishay-Dale | CRCW0402115KFKED (http://www.vishay.com/docs/20035/dcrcwe3.pdf) Series= CRCW..e3 | Res= 115.0 kOhm Power= 63.0 mW Tolerance= 1.0% | 1 | $0.01
0402 3 mm²
U1 | Texas Instruments | LMR54410FDBVR (http://www.ti.com/product/LMR54410) | Switcher | 1 | $0.28

DBV0006A 15 mm²

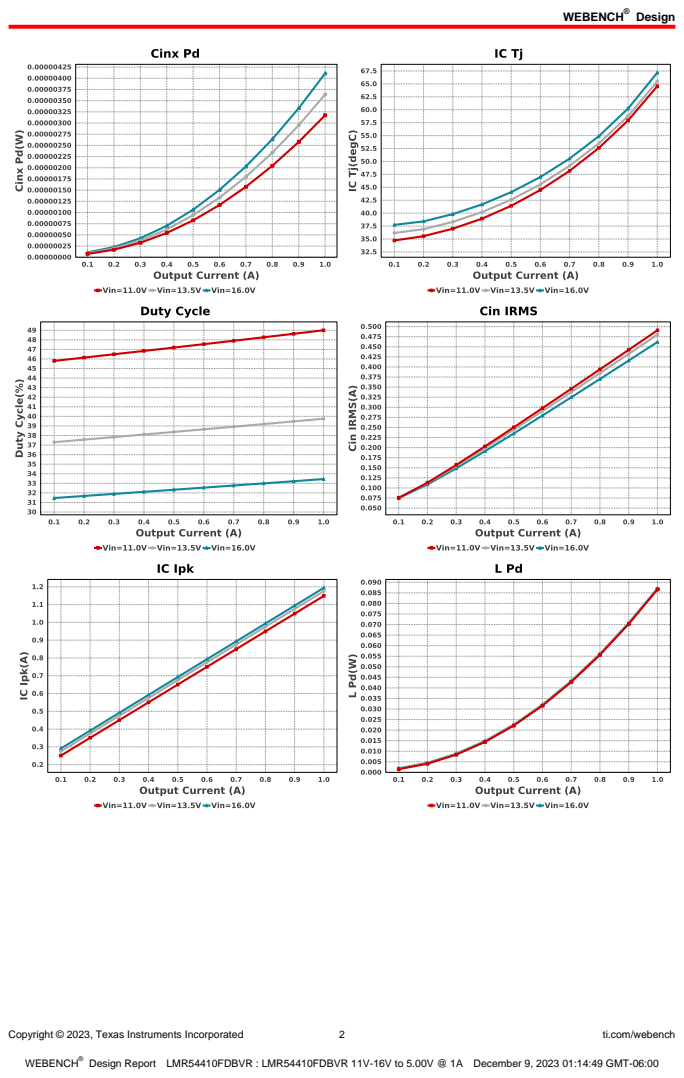
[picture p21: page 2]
Design; Copyright © 2023, Texas Instruments Incorporated; ti.com/webench

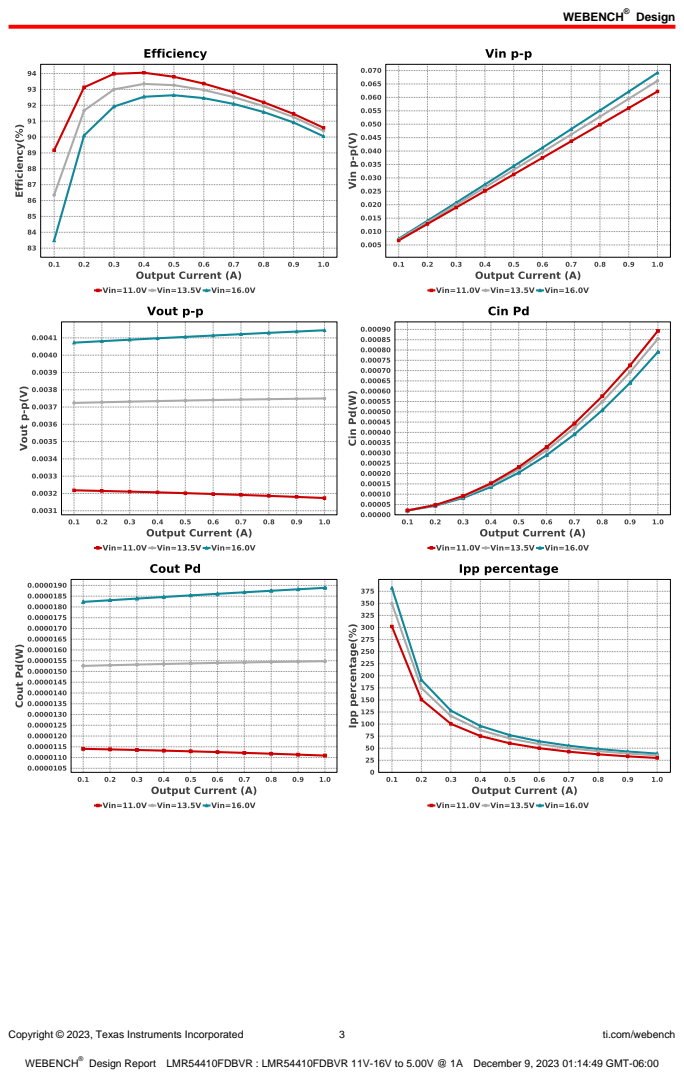
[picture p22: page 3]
Copyright © 2023, Texas Instruments Incorporated; ti.com/webench

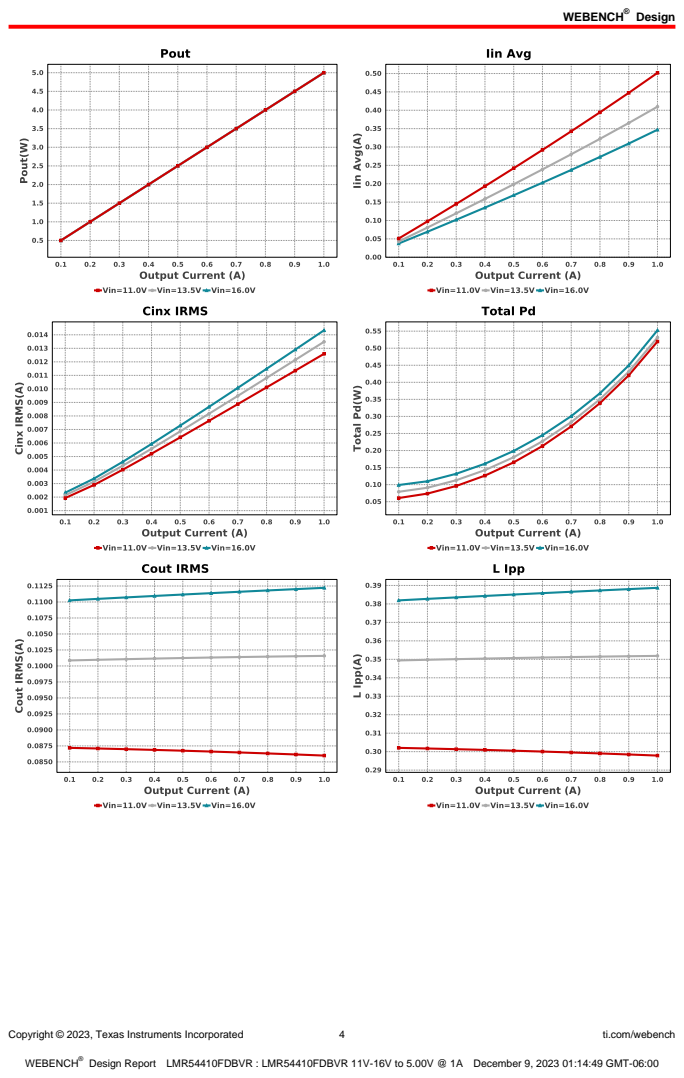
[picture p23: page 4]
Copyright © 2023, Texas Instruments Incorporated; ti.com/webench

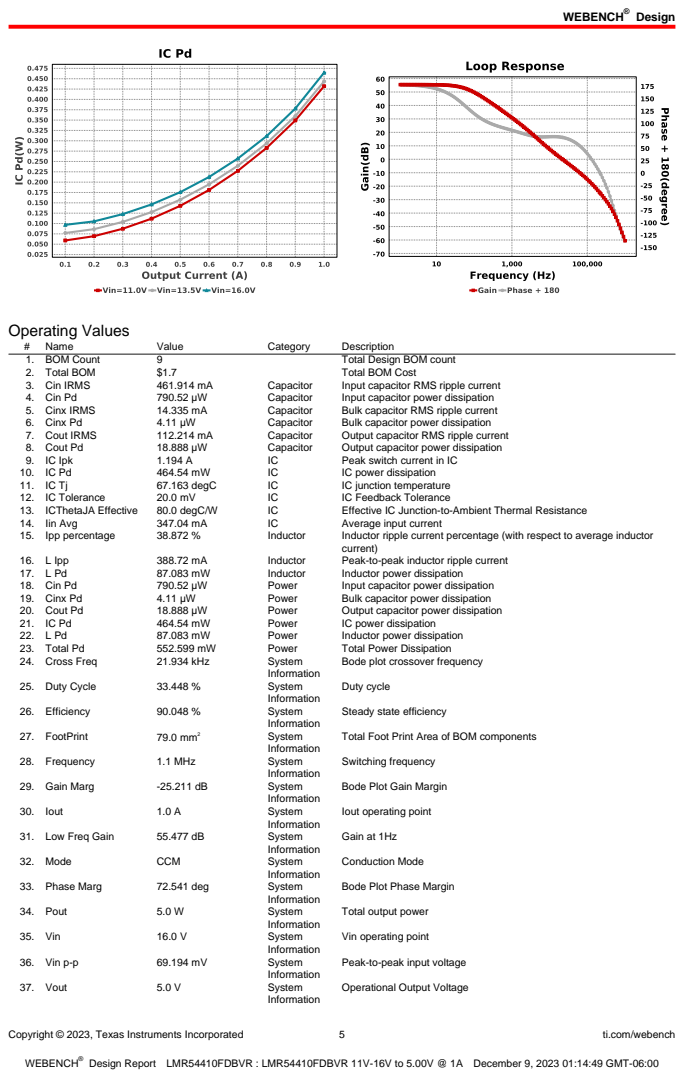
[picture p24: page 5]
Copyright © 2023, Texas Instruments Incorporated; ti.com/webench; Operating Values; Name; Value; Category; Description; 1. BOM Count; Total Design BOM count; 2. Total BOM; Total BOM Cost; 3. Cin IRMS; Capacitor; Input capacitor RMS ripple current; 4. Cin Pd; Input capacitor power dissipation; 5. Cinx IRMS; Bulk capacitor RMS ripple current; 6. Cinx Pd; Bulk capacitor power dissipation; 7. Cout IRMS; Output capacitor RMS ripple current; 8. Cout Pd; Output capacitor power dissipation; 9. IC Ipk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

Bode plot crossover frequency

Steady state efficiency

Total Foot Print Area of BOM components

Bode Plot Gain Margin

Iout operating point

Bode Plot Phase Margin

Total output power

Vin operating point

Peak-to-peak input voltage

Operational Output Voltage

Copyright © 2023, Texas Instruments Incorporated | 6 | ti.com/webench
# | Name | Value | Category | Description

38. Vout Actual | 4.963 V | System
| | | Information | Vout Actual calculated based on selected voltage divider resistors
39. Vout Tolerance | 4.237 % | System
| | | Information | Vout Tolerance based on IC Tolerance (no load) and voltage divider resistors if applicable
40. Vout p-p | 4.144 mV | System
| | | Information | Peak-to-peak output ripple voltage

## Design Inputs

Name | Value | Description
Iout | 1.0 | Maximum Output Current
VinMax | 16.0 | Maximum input voltage
VinMin | 11.0 | Minimum input voltage
Vout | 5.0 | Output Voltage
| base_pn | | LMR54410F | Base Product Number
source | DC | Input Source Type
Ta | 30.0 | Ambient temperature


Copyright © 2023, Texas Instruments Incorporated | 7 | ti.com/webench

## Assembly
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

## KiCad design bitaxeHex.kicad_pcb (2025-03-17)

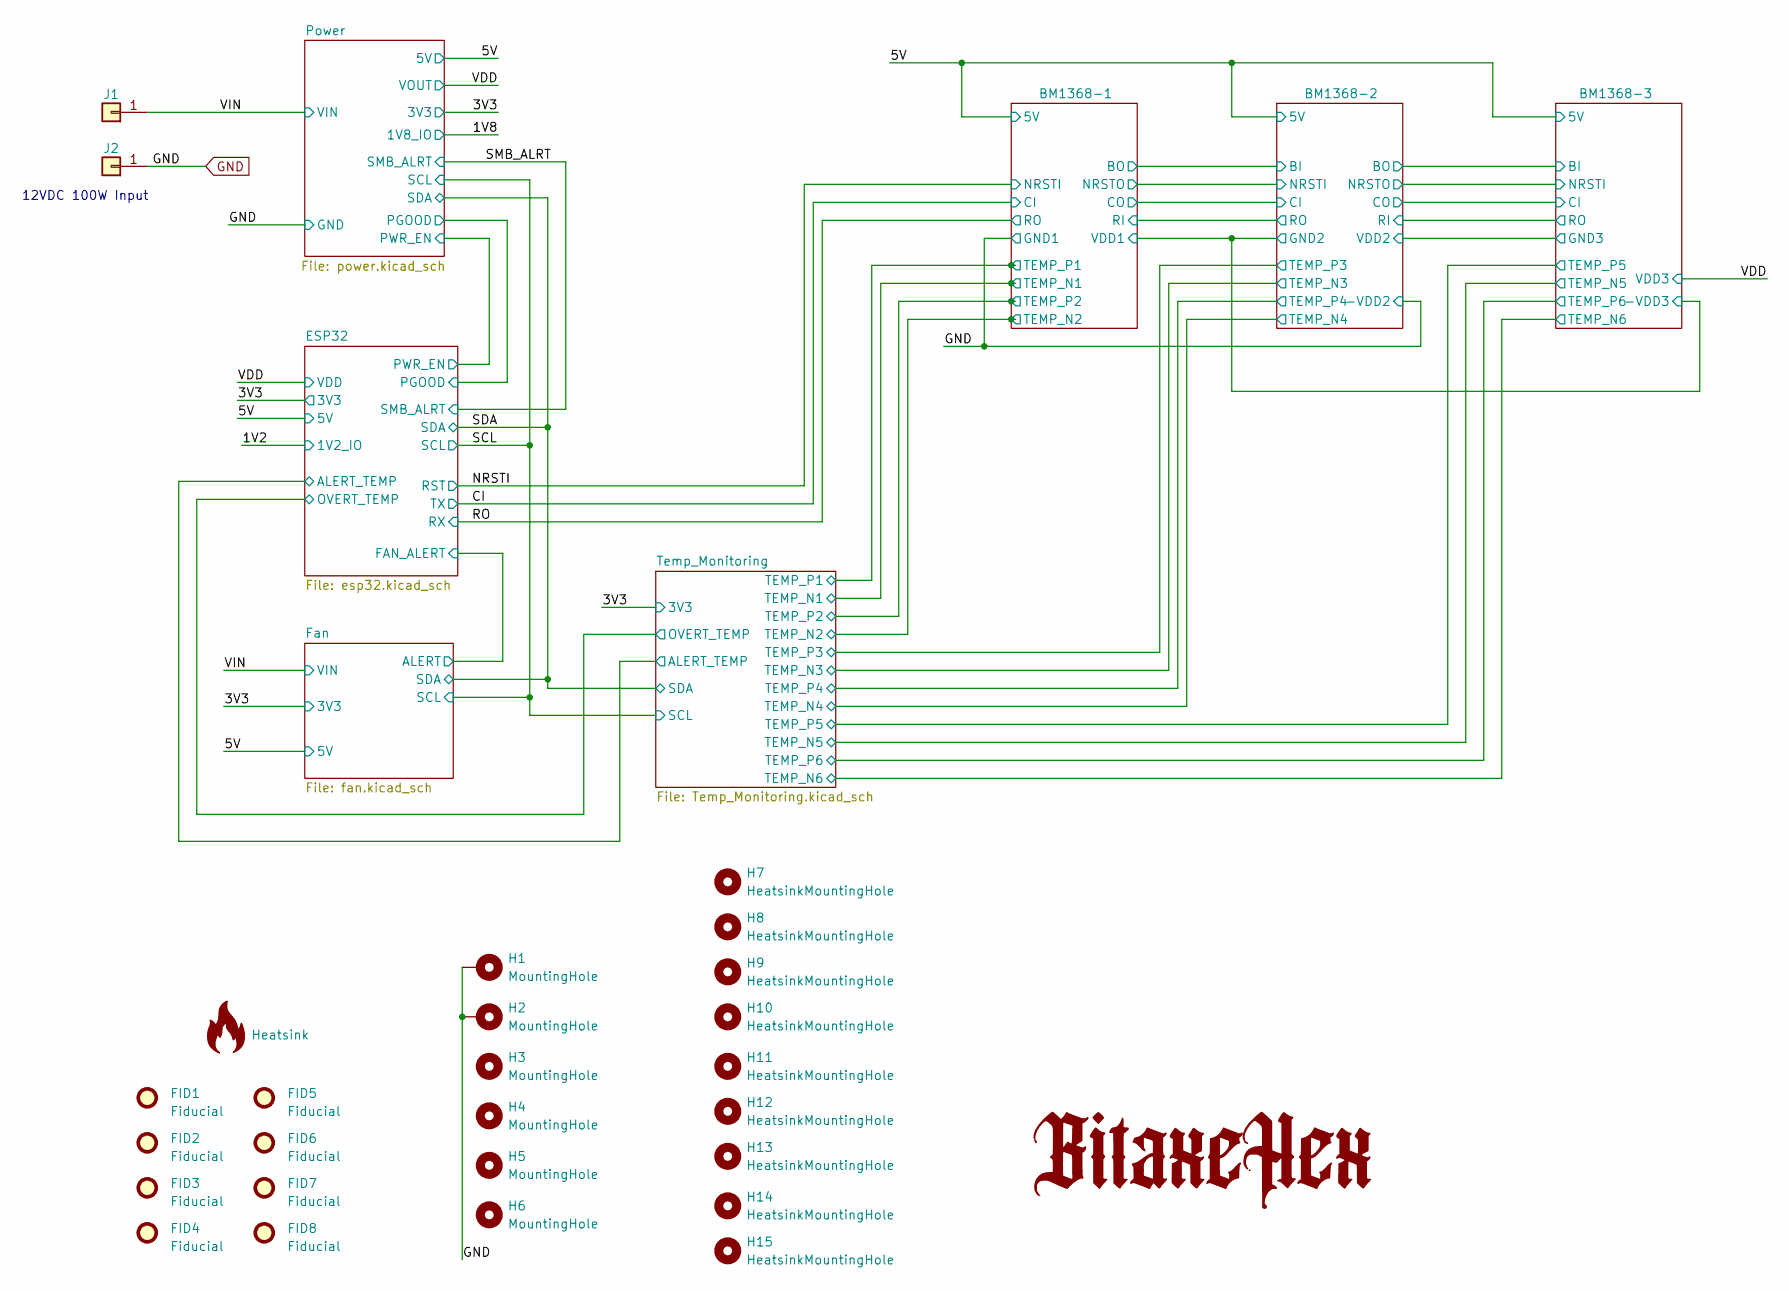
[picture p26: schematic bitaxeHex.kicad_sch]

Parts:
FID1, FID2, FID3, FID4, FID5, FID6, FID7, FID8: Fiducial; Fiducial_1mm_Mask2mm
H1, H2, H3, H4, H5, H6: MountingHole; MountingHole_3mm_Pad_Via
H7, H8, H9, H10, H11, H12, H13, H14, H15: HeatsinkMountingHole; 3.1mm_mounting
HS1: Heatsink; hex-heatsink
J1, J2: Screw Terminal; 7771-screw-terminal; PARTNO 36-7771

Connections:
/VIN: J1.1; also elsewhere on the board
GND: H1.1, H2.1, J2.1; also elsewhere on the board

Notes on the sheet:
12VDC 100W Input

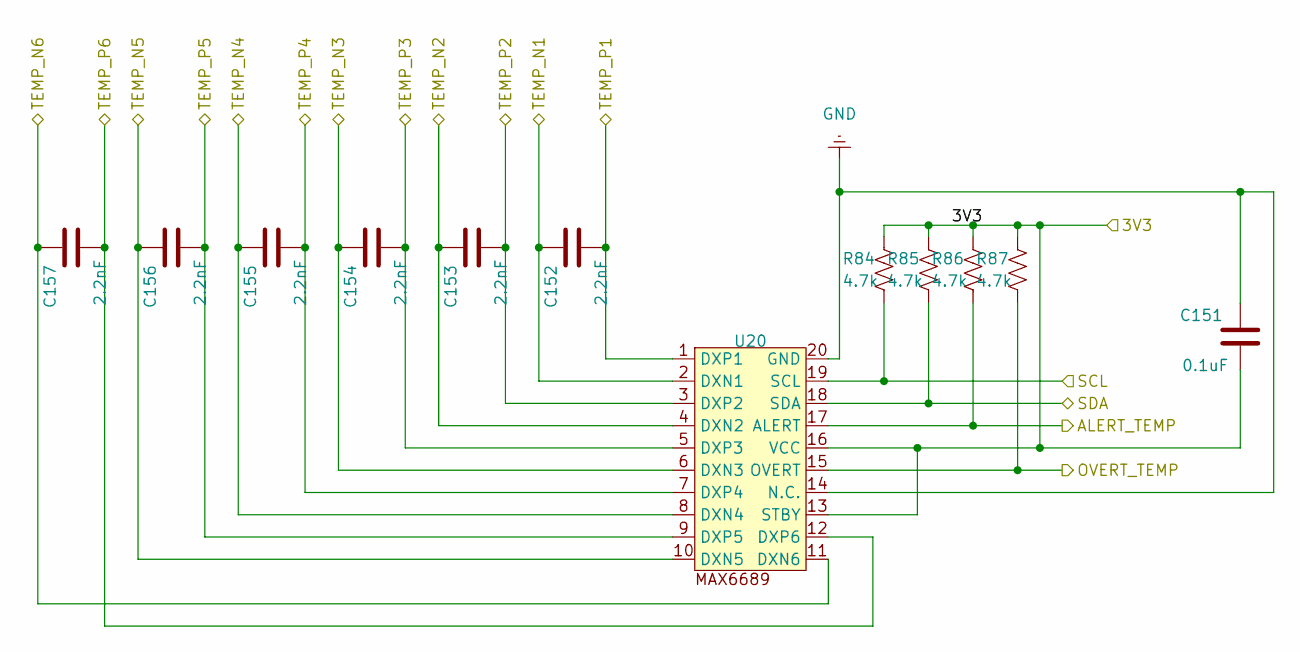
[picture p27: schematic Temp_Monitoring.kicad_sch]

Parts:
C151: 0.1uF; C_0402_1005Metric; PARTNO KGM05AR71C104KH
C152, C153, C154, C155, C156, C157: 2.2nF; C_0402_1005Metric; PARTNO CC0402KRX7R9BB222
R84, R85, R86, R87: 4.7k; R_0402_1005Metric; PARTNO RT0402BRD074K7L
U20: MAX6689UP9A+; PARTNO MAX6689UP9A+

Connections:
/3V3: C151.1, R84.2, R85.2, R86.2, R87.2, U20.13 (STBY), U20.16 (VCC); also elsewhere on the board
/BM1368-1/TEMP_N1: C152.2, U20.2 (DXN1); also elsewhere on the board
/BM1368-1/TEMP_N2: C153.2, U20.4 (DXN2); also elsewhere on the board
/BM1368-1/TEMP_P1: C152.1, U20.1 (DXP1); also elsewhere on the board
/BM1368-1/TEMP_P2: C153.1, U20.3 (DXP2); also elsewhere on the board
/BM1368-2/TEMP_N3: C154.2, U20.6 (DXN3); also elsewhere on the board
/BM1368-2/TEMP_N4: C155.2, U20.8 (DXN4); also elsewhere on the board
/BM1368-2/TEMP_P3: C154.1, U20.5 (DXP3); also elsewhere on the board
/BM1368-2/TEMP_P4: C155.1, U20.7 (DXP4); also elsewhere on the board
/BM1368-3/TEMP_N5: C156.2, U20.10 (DXN5); also elsewhere on the board
/BM1368-3/TEMP_N6: C157.2, U20.11 (DXN6); also elsewhere on the board
/BM1368-3/TEMP_P5: C156.1, U20.9 (DXP5); also elsewhere on the board
/BM1368-3/TEMP_P6: C157.1, U20.12 (DXP6); also elsewhere on the board
/ESP32/ALERT_TEMP: R86.1, U20.17 (ALERT); also elsewhere on the board
/ESP32/OVERT_TEMP: R87.1, U20.15 (OVERT); also elsewhere on the board
/SCL: R84.1, U20.19 (SCL); also elsewhere on the board
/SDA: R85.1, U20.18 (SDA); also elsewhere on the board
GND: C151.2, U20.14 (N.C.), U20.20 (GND); also elsewhere on the board

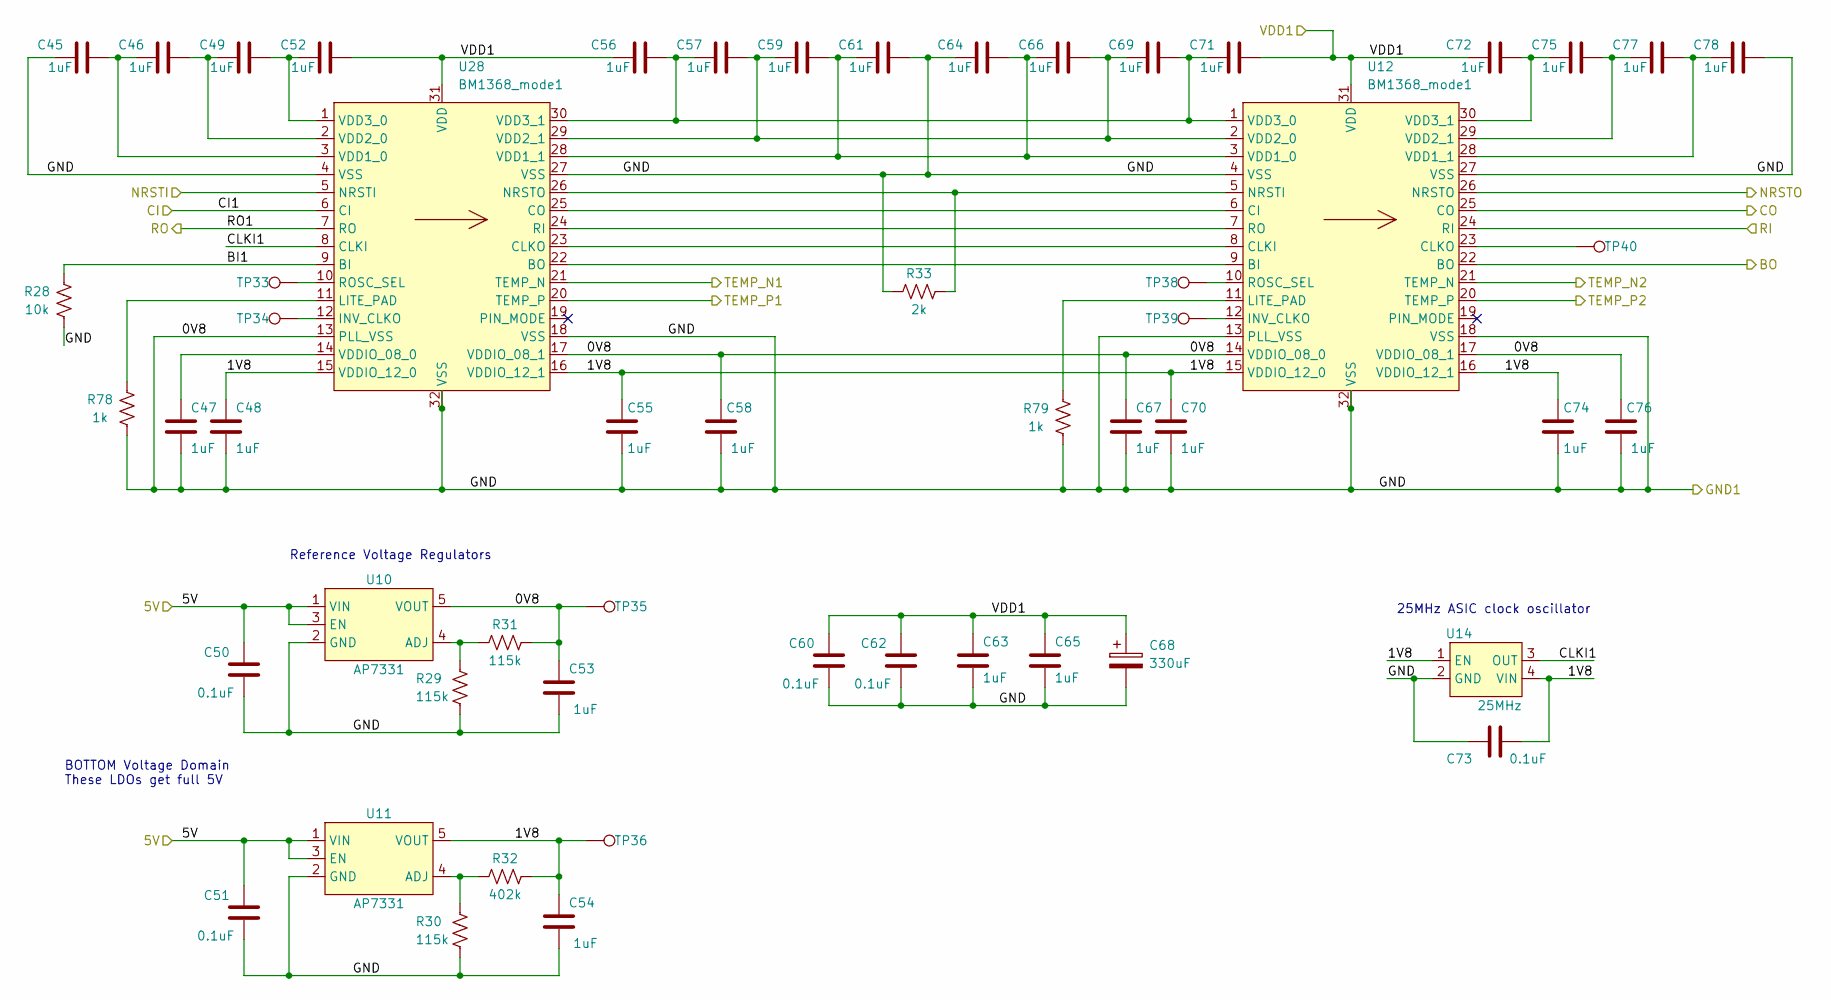
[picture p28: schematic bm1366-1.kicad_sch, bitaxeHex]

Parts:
C45, C46, C47, C48, C49, C52, C53, C54, C55, C56, C57, C58, C59, C61, C63, C64, C65, C66, C67, C69, C70, C71, C72, C74, C75, C76, C77, C78: 1uF; C_0402_1005Metric; PARTNO EMK105BJ105MV-F
C50, C51, C60, C62, C73: 0.1uF; C_0402_1005Metric; PARTNO KGM05AR71C104KH
C68: 330uF; CP_EIA-7343-31_Kemet-D_Pad2.25x2.55mm_HandSolder; PARTNO 293D337X9010E2TE3
R28: 10k; R_0402_1005Metric; PARTNO RC0402JR-0710KL
R29, R30, R31: 115k; R_0402_1005Metric; PARTNO RC0402FR-07115KL
R32: 402k; R_0402_1005Metric; PARTNO RC0402FR-07402KL
R33: 2k; R_0402_1005Metric; PARTNO RT0402BRD072KL
R78, R79: 1k; R_0402_1005Metric; PARTNO RC0402FR-071KL
TP33, TP34, TP35, TP36, TP38, TP39, TP40: TestPoint; TestPoint_Pad_D1.0mm
U10, U11: AP7331; TSOT-23-5; PARTNO AP7331-WG-7
U12, U28: BM1368_mode1; BM1368
U14: 25MHz; O 25,0-JO32-B-1V3-1-T1-LF; PARTNO O 25,0-JO32-B-1V3-1-T1-LF

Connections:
/5V: C50.2, C51.2, U10.1 (VIN), U10.3 (EN), U11.1 (VIN), U11.3 (EN); also elsewhere on the board
/BM1368-1/1V8: C48.1, C54.1, C55.1, C70.1, C73.1, C74.1, R32.1, TP36.1, U11.5 (VOUT), U12.15 (VDDIO_12_0), U12.16 (VDDIO_12_1), U14.1 (EN), U14.4 (VIN), U28.15 (VDDIO_12_0), U28.16 (VDDIO_12_1)
/BM1368-1/BI1: R28.2, U28.9 (BI)
/BM1368-1/BO: U12.22 (BO); also elsewhere on the board
/BM1368-1/CLKI1: U14.3 (OUT), U28.8 (CLKI)
/BM1368-1/CO: U12.25 (CO); also elsewhere on the board
/BM1368-1/NRSTO: U12.26 (NRSTO); also elsewhere on the board
/BM1368-1/RI: U12.24 (RI); also elsewhere on the board
/BM1368-1/TEMP_N1: U28.21 (TEMP_N); also elsewhere on the board
/BM1368-1/TEMP_N2: U12.21 (TEMP_N); also elsewhere on the board
/BM1368-1/TEMP_P1: U28.20 (TEMP_P); also elsewhere on the board
/BM1368-1/TEMP_P2: U12.20 (TEMP_P); also elsewhere on the board
/BM1368-1/VDD1: C52.2, C56.1, C60.2, C62.2, C63.1, C65.1, C68.1, C71.2, C72.1, U12.31 (VDD), U28.31 (VDD); also elsewhere on the board
/CI: U28.6 (CI); also elsewhere on the board
/NRSTI: U28.5 (NRSTI); also elsewhere on the board
/RO: U28.7 (RO); also elsewhere on the board
GND: C45.1, C47.2, C48.2, C50.1, C51.1, C53.1, C53.2, C54.2, C55.2, C58.1, C58.2, C60.1, C61.2, C62.1, C63.2, C64.1, C65.2, C67.1, C67.2, C68.2, C70.2, C73.2, C74.2, C76.1, C76.2, C78.2, R28.1, R29.1, R30.1, R31.2, R33.1, R78.1, R79.1, TP35.1, U10.2 (GND), U10.5 (VOUT), U11.2 (GND), U12.4 (VSS), U12.13 (PLL_VSS), U12.14 (VDDIO_08_0), U12.17 (VDDIO_08_1), U12.18 (VSS), U12.27 (VSS), U12.32 (VSS), U14.2 (GND), U28.4 (VSS), U28.13 (PLL_VSS), U28.17 (VDDIO_08_1), U28.18 (VSS), U28.27 (VSS), U28.32 (VSS); also elsewhere on the board
unnamed: R29.2, R31.1, U10.4 (ADJ)
unnamed: R30.2, R32.2, U11.4 (ADJ)
unnamed: U12.9 (BI), U28.22 (BO)
unnamed: U12.6 (CI), U28.25 (CO)
unnamed: U12.8 (CLKI), U28.23 (CLKO)
unnamed: TP40.1, U12.23 (CLKO)
unnamed: TP39.1, U12.12 (INV_CLKO)
unnamed: R79.2, U12.11 (LITE_PAD)
unnamed: R33.2, U12.5 (NRSTI), U28.26 (NRSTO)
unnamed: U12.7 (RO), U28.24 (RI)
unnamed: TP38.1, U12.10 (ROSC_SEL)
unnamed: C59.2, C61.1, C64.2, C66.1, U12.3 (VDD1_0), U28.28 (VDD1_1)
unnamed: C77.2, C78.1, U12.28 (VDD1_1)
unnamed: C57.2, C59.1, C66.2, C69.1, U12.2 (VDD2_0), U28.29 (VDD2_1)
unnamed: C75.2, C77.1, U12.29 (VDD2_1)
unnamed: C56.2, C57.1, C69.2, C71.1, U12.1 (VDD3_0), U28.30 (VDD3_1)
unnamed: C72.2, C75.1, U12.30 (VDD3_1)
unnamed: TP34.1, U28.12 (INV_CLKO)
unnamed: R78.2, U28.11 (LITE_PAD)
unnamed: TP33.1, U28.10 (ROSC_SEL)
unnamed: C45.2, C46.1, U28.3 (VDD1_0)
unnamed: C46.2, C49.1, U28.2 (VDD2_0)
unnamed: C49.2, C52.1, U28.1 (VDD3_0)
unnamed: C47.1, U28.14 (VDDIO_08_0)

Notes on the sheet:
Reference Voltage Regulators
BOTTOM Voltage Domain These LDOs get full 5V
25MHz ASIC clock oscillator

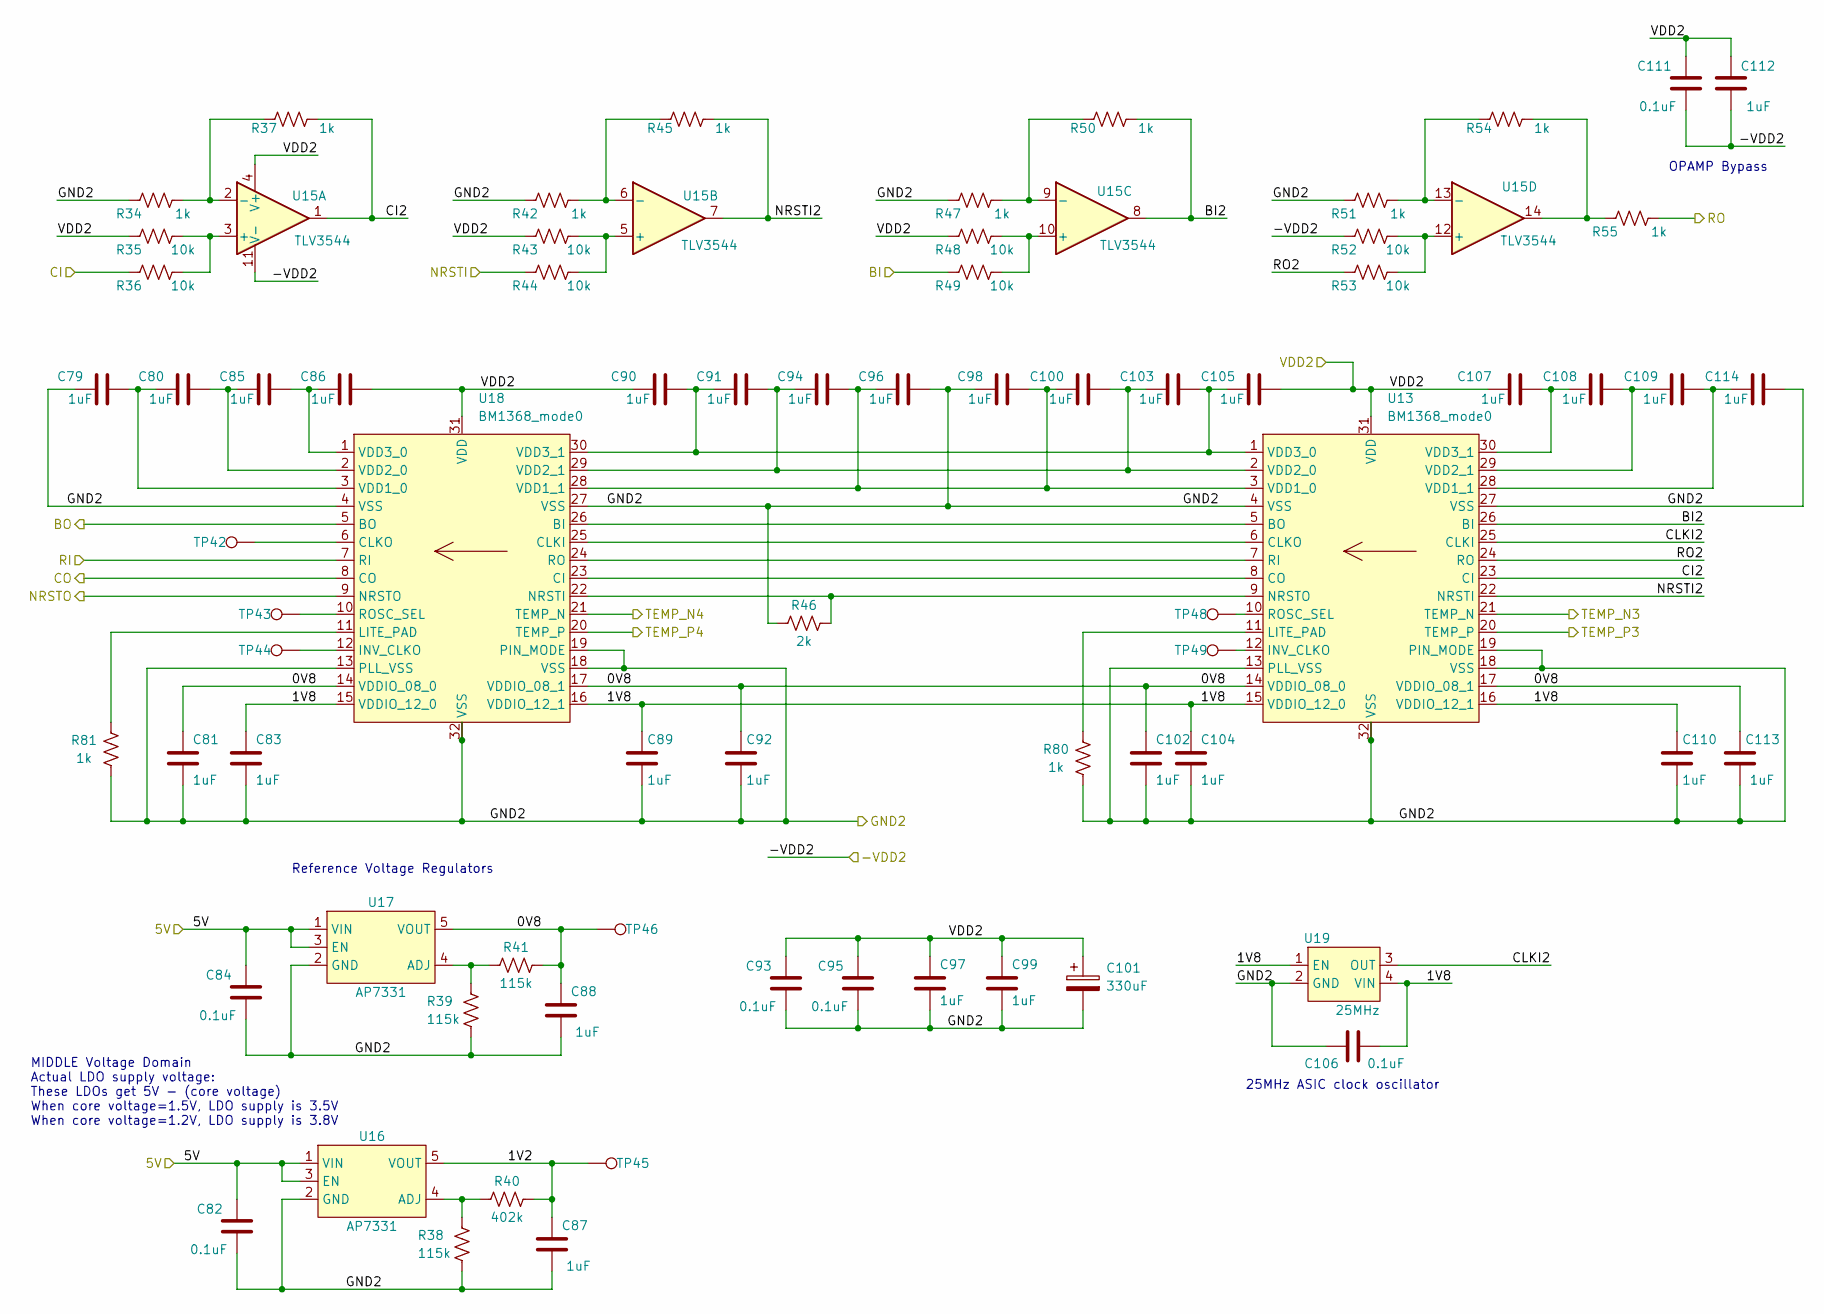
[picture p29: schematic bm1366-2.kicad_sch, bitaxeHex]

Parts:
C79, C80, C81, C83, C85, C86, C87, C88, C89, C90, C91, C92, C94, C96, C97, C98, C99, C100, C102, C103, C104, C105, C107, C108, C109, C110, C112, C113, C114: 1uF; C_0402_1005Metric; PARTNO EMK105BJ105MV-F
C82, C84, C93, C95, C106, C111: 0.1uF; C_0402_1005Metric; PARTNO KGM05AR71C104KH
C101: 330uF; CP_EIA-7343-31_Kemet-D_Pad2.25x2.55mm_HandSolder; PARTNO 293D337X9010E2TE3
R34, R37, R42, R45, R47, R50, R51, R54, R55, R80, R81: 1k; R_0402_1005Metric; PARTNO RC0402FR-071KL
R35, R36, R43, R44, R48, R49, R52, R53: 10k; R_0402_1005Metric; PARTNO RC0402JR-0710KL
R38, R39, R41: 115k; R_0402_1005Metric; PARTNO RC0402FR-07115KL
R40: 402k; R_0402_1005Metric; PARTNO RC0402FR-07402KL
R46: 2k; R_0402_1005Metric; PARTNO RT0402BRD072KL
TP42, TP43, TP44, TP45, TP46, TP48, TP49: TestPoint; TestPoint_Pad_D1.0mm
U13, U18: BM1368_mode0; BM1368
U15: TLV3544; TSSOP-14_4.4x5mm_P0.65mm; PARTNO TLV3544IPWR
U16, U17: AP7331; TSOT-23-5; PARTNO AP7331-WG-7
U19: 25MHz; O 25,0-JO32-B-1V3-1-T1-LF; PARTNO O 25,0-JO32-B-1V3-1-T1-LF

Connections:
/5V: C82.2, C84.2, U16.1 (VIN), U16.3 (EN), U17.1 (VIN), U17.3 (EN); also elsewhere on the board
/BM1368-1/BO: R49.1; also elsewhere on the board
/BM1368-1/CO: R36.1; also elsewhere on the board
/BM1368-1/NRSTO: R44.1; also elsewhere on the board
/BM1368-1/RI: R55.1; also elsewhere on the board
/BM1368-1/VDD1: C79.1, C81.2, C82.1, C83.2, C84.1, C87.2, C88.2, C89.2, C92.2, C93.1, C95.1, C96.2, C97.2, C98.1, C99.2, C101.2, C102.2, C104.2, C106.2, C110.2, C113.2, C114.2, R34.2, R38.1, R39.1, R42.2, R46.1, R47.2, R51.2, R80.1, R81.1, U13.4 (VSS), U13.13 (PLL_VSS), U13.18 (VSS), U13.19 (PIN_MODE), U13.27 (VSS), U13.32 (VSS), U16.2 (GND), U17.2 (GND), U18.4 (VSS), U18.13 (PLL_VSS), U18.18 (VSS), U18.19 (PIN_MODE), U18.27 (VSS), U18.32 (VSS), U19.2 (GND); also elsewhere on the board
/BM1368-2/0V8: C81.1, C88.1, C92.1, C102.1, C113.1, R41.2, TP46.1, U13.14 (VDDIO_08_0), U13.17 (VDDIO_08_1), U17.5 (VOUT), U18.14 (VDDIO_08_0), U18.17 (VDDIO_08_1)
/BM1368-2/BI2: R50.1, U13.26 (BI), U15.8
/BM1368-2/BO: U18.5 (BO); also elsewhere on the board
/BM1368-2/CI2: R37.1, U13.23 (CI), U15.1
/BM1368-2/CLKI2: U13.25 (CLKI), U19.3 (OUT)
/BM1368-2/CO: U18.8 (CO); also elsewhere on the board
/BM1368-2/NRSTI2: R45.1, U13.22 (NRSTI), U15.7
/BM1368-2/NRSTO: U18.9 (NRSTO); also elsewhere on the board
/BM1368-2/RI: U18.7 (RI); also elsewhere on the board
/BM1368-2/RO2: R53.1, U13.24 (RO)
/BM1368-2/TEMP_N3: U13.21 (TEMP_N); also elsewhere on the board
/BM1368-2/TEMP_N4: U18.21 (TEMP_N); also elsewhere on the board
/BM1368-2/TEMP_P3: U13.20 (TEMP_P); also elsewhere on the board
/BM1368-2/TEMP_P4: U18.20 (TEMP_P); also elsewhere on the board
/BM1368-2/VDD2: C86.2, C90.1, C93.2, C95.2, C97.1, C99.1, C101.1, C105.2, C107.1, C111.2, C112.2, R35.2, R43.1, R48.1, U13.31 (VDD), U15.4 (V+), U18.31 (VDD); also elsewhere on the board
GND: C111.1, C112.1, R52.1, U15.11 (V-); also elsewhere on the board
unnamed: R54.1, R55.2, U15.14
unnamed: U13.5 (BO), U18.26 (BI)
unnamed: U13.6 (CLKO), U18.25 (CLKI)
unnamed: U13.8 (CO), U18.23 (CI)
unnamed: TP49.1, U13.12 (INV_CLKO)
unnamed: R80.2, U13.11 (LITE_PAD)
unnamed: R46.2, U13.9 (NRSTO), U18.22 (NRSTI)
unnamed: U13.7 (RI), U18.24 (RO)
unnamed: TP48.1, U13.10 (ROSC_SEL)
unnamed: C94.2, C96.1, C98.2, C100.1, U13.3 (VDD1_0), U18.28 (VDD1_1)
unnamed: C109.2, C114.1, U13.28 (VDD1_1)
unnamed: C91.2, C94.1, C100.2, C103.1, U13.2 (VDD2_0), U18.29 (VDD2_1)
unnamed: C108.2, C109.1, U13.29 (VDD2_1)
unnamed: C90.2, C91.1, C103.2, C105.1, U13.1 (VDD3_0), U18.30 (VDD3_1)
unnamed: C107.2, C108.1, U13.30 (VDD3_1)
unnamed: R35.1, R36.2, U15.3 (+)
unnamed: R34.1, R37.2, U15.2 (-)
unnamed: R43.2, R44.2, U15.5 (+)
unnamed: R42.1, R45.2, U15.6 (-)
unnamed: R48.2, R49.2, U15.10 (+)
unnamed: R47.1, R50.2, U15.9 (-)
unnamed: R52.2, R53.2, U15.12 (+)
unnamed: R51.1, R54.2, U15.13 (-)
unnamed: R38.2, R40.2, U16.4 (ADJ)
unnamed: R39.2, R41.1, U17.4 (ADJ)
unnamed: TP42.1, U18.6 (CLKO)
unnamed: TP44.1, U18.12 (INV_CLKO)
unnamed: R81.2, U18.11 (LITE_PAD)
unnamed: TP43.1, U18.10 (ROSC_SEL)
unnamed: C79.2, C80.1, U18.3 (VDD1_0)
unnamed: C80.2, C85.1, U18.2 (VDD2_0)
unnamed: C85.2, C86.1, U18.1 (VDD3_0)

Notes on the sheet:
MIDDLE Voltage Domain Actual LDO supply voltage: These LDOs get 5V - (core voltage) When core voltage=1.5V, LDO supply is 3.5V When core voltage=1.2V, LDO supply is 3.8V
Reference Voltage Regulators
25MHz ASIC clock oscillator
OPAMP Bypass

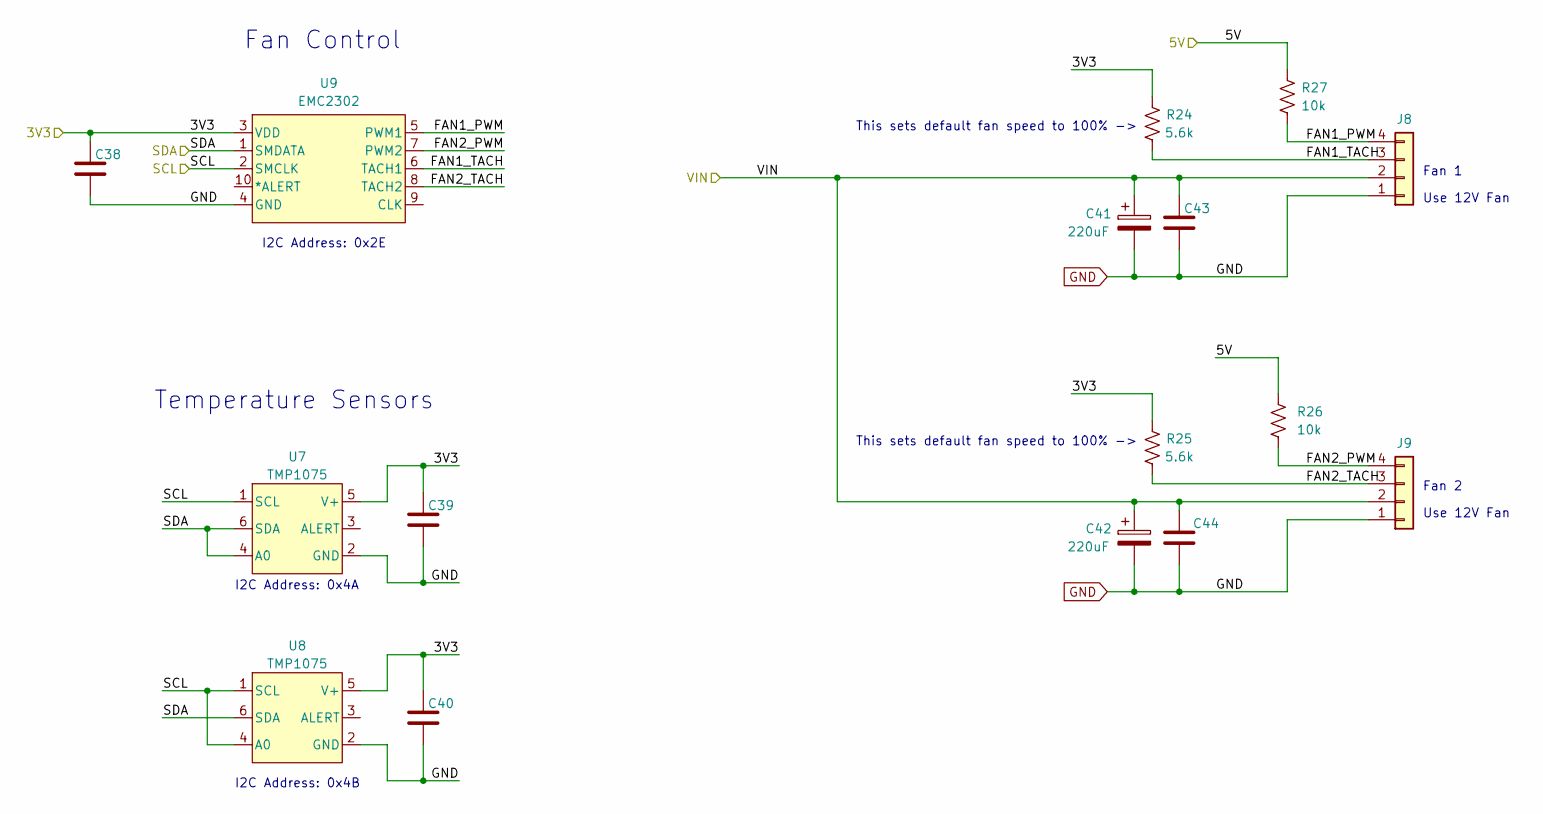
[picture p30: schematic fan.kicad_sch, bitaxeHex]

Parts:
C38, C39, C40, C43, C44: 311-3342-1-ND; C_0402_1005Metric; PARTNO KGM05AR71C104KH
C41, C42: 220uF; CP_Elec_6.3x7.7; PARTNO 865080345012
J8, J9: Conn_01x04; 470531000; PARTNO 0470531000
R24, R25: 5.6k; R_0402_1005Metric; PARTNO RC0402FR-135K6L
R26, R27: 10k; R_0402_1005Metric; PARTNO RC0402JR-0710KL
U7, U8: TMP1075; SOT5X3-6_DRL_TEX; PARTNO TMP1075NDRLR
U9: EMC2302; MSOP-10_3x3mm_P0.5mm; PARTNO EMC2302-2-AIZL-TR

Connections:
/3V3: C38.1, C39.1, C40.1, R24.2, R25.2, U7.5 (V+), U8.5 (V+), U9.3 (VDD); also elsewhere on the board
/5V: R26.2, R27.2; also elsewhere on the board
/Fan/FAN1_PWM: J8.4, R27.1, U9.5 (PWM1)
/Fan/FAN1_TACH: J8.3, R24.1, U9.6 (TACH1)
/Fan/FAN2_PWM: J9.4, R26.1, U9.7 (PWM2)
/Fan/FAN2_TACH: J9.3, R25.1, U9.8 (TACH2)
/SCL: U7.1 (SCL), U8.1 (SCL), U8.4 (A0), U9.2 (SMCLK); also elsewhere on the board
/SDA: U7.4 (A0), U7.6 (SDA), U8.6 (SDA), U9.1 (SMDATA); also elsewhere on the board
/VIN: C41.1, C42.1, C43.1, C44.1, J8.2, J9.2; also elsewhere on the board
GND: C38.2, C39.2, C40.2, C41.2, C42.2, C43.2, C44.2, J8.1, J9.1, U7.2 (GND), U8.2 (GND), U9.4 (GND); also elsewhere on the board

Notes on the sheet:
I2C Address: 0x2E
Temperature Sensors
I2C Address: 0x4A
Fan Control
Fan 1
Use 12V Fan
This sets default fan speed to 100% ->
Fan 2
I2C Address: 0x4B

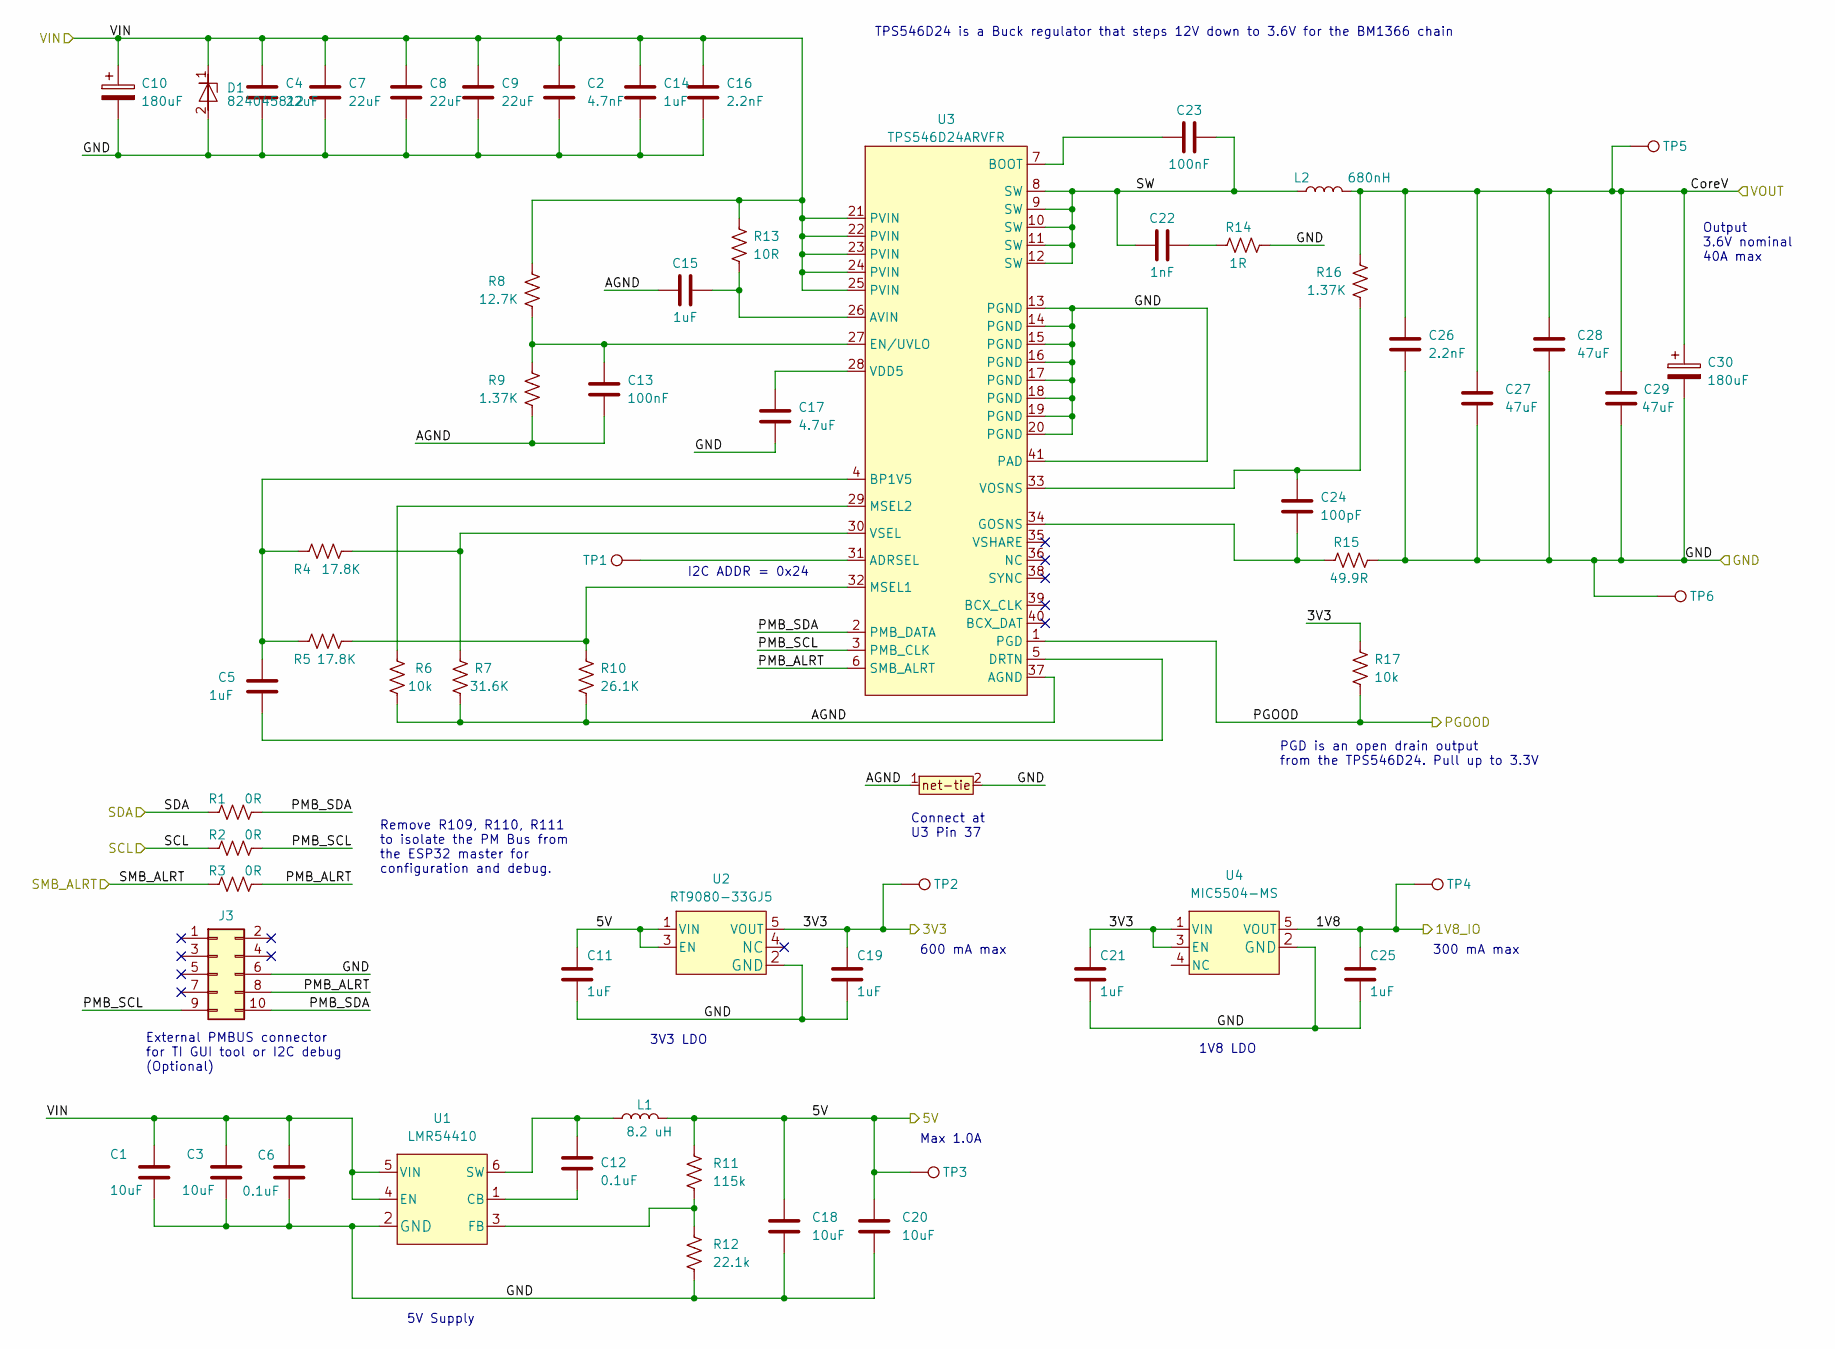
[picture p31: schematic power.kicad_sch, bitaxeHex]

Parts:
C1, C3, C18, C20: 10uF; C_0805_2012Metric; PARTNO GRM21BR61H106ME43L
C2: 4.7nF; C_0402_1005Metric; PARTNO GRM155R71E472KA01D
C4, C7, C8, C9: 22uF; C_1210_3225Metric; PARTNO GRM32ER61E226KE15L
C5: 1uF; C_0603_1608Metric; PARTNO GRM188R60J105KA01D
C6: 0.1uF; C_0603_1608Metric; PARTNO KGM15BR71H104KT
C10, C30: 180uF; CP_Elec_6.3x5.9; PARTNO 16SVPF180M
C11, C19, C21, C25: 1uF; C_0402_1005Metric; PARTNO EMK105BJ105MV-F
C12: 0.1uF; C_0402_1005Metric; PARTNO KGM05AR71C104KH
C13: 100nF; C_0402_1005Metric; PARTNO GRM155R71A104KA01D
C14, C15: 1uF; C_0805_2012Metric; PARTNO TMK212BJ105KG-T
C16, C26: 2.2nF; C_0402_1005Metric; PARTNO GRM155R61H222KA01D
C17: 4.7uF; C_0402_1005Metric; PARTNO GRM155R61A475MEAAD
C22: 1nF; C_0805_2012Metric; PARTNO CC0805KRX7R9BB102
C23: 100nF; C_0805_2012Metric; PARTNO KGM21NR71E104KT
C24: 100pF; C_0402_1005Metric; PARTNO 885012005013
C27, C28, C29: 47uF; C_1210_3225Metric; PARTNO GRM32ER61C476KE15L
D1: 824045812; PARTNO 824045812
J3: Conn_02x05_Odd_Even; PinHeader_2x05_P2.54mm_Vertical
L1: 8.2 uH; 74438357082; PARTNO 78438357082
L2: 680nH; L_Coilcraft_XAL1010-XXX; PARTNO XAL1010-681MED; Mouser 994-XAL1010-681MED
R1, R2, R3: 0R; R_0402_1005Metric; PARTNO RC0402JR-070RL
R4, R5: 17.8K; R_0402_1005Metric; PARTNO RMCF0402FT17K8
R6: 10k; R_0402_1005Metric; PARTNO RMCF0402FT10K0
R7: 31.6K; R_0402_1005Metric; PARTNO RC0402FR-0731K6L
R8: 12.7K; R_0402_1005Metric; PARTNO RC0402FR-0712K7L
R9, R16: 1.37K; R_0402_1005Metric; PARTNO RC0402FR-071K37L
R10: 26.1K; R_0402_1005Metric; PARTNO RC0402FR-0726K1L
R11: 115k; R_0402_1005Metric; PARTNO RC0402FR-07115KL
R12: 22.1k; R_0402_1005Metric; PARTNO RC0402FR-0722K1L
R13: 10R; R_0402_1005Metric; PARTNO RC0402FR-0710RL
R14: 1R; R_1206_3216Metric; PARTNO CSR1206FT1R00
R15: 49.9R; R_0402_1005Metric; PARTNO RC0402FR-0749R9L
R17: 10k; R_0402_1005Metric; PARTNO RC0402JR-0710KL
T1: net-tie; Net-Tie-0.25mm
TP1: TestPoint; TestPoint_Pad_D0.8mm
TP2, TP3, TP4, TP5, TP6: TestPoint; TestPoint_Pad_D1.0mm
U1: LMR54410; SOT-23-6; PARTNO LMR54410FDBVR
U2: RT9080-33GJ5; PARTNO RT9080-33GJ5
U3: TPS546D24ARVFR; LQFN40-CLIP; PARTNO TPS546D24ARVFR
U4: MIC5504-MS; SOT-23-5_HandSoldering; PARTNO MIC5504-1.8YM5-TR

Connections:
/1V8: C25.1, TP4.1, U4.5 (VOUT)
/3V3: C19.1, C21.1, R17.2, TP2.1, U2.5 (VOUT), U4.1 (VIN), U4.3 (EN); also elsewhere on the board
/5V: C11.1, C18.1, C20.1, L1.2, R11.1, TP3.1, U2.1 (VIN), U2.3 (EN); also elsewhere on the board
/Power/AGND: C13.2, C15.1, R6.1, R7.2, R9.2, R10.2, T1.1, U3.37 (AGND)
/Power/PGOOD: R17.1, U3.1 (PGD); also elsewhere on the board
/Power/PMB_ALRT: J3.8, R3.2, U3.6 (SMB_ALRT)
/Power/PMB_SCL: J3.9, R2.2, U3.3 (PMB_CLK)
/Power/PMB_SDA: J3.10, R1.2, U3.2 (PMB_DATA)
/Power/SW: C22.1, C23.2, L2.1, U3.8 (SW), U3.9 (SW), U3.10 (SW), U3.11 (SW), U3.12 (SW)
/SCL: R2.1; also elsewhere on the board
/SDA: R1.1; also elsewhere on the board
/SMB_ALRT: R3.1; also elsewhere on the board
/VDD: C26.1, C27.1, C28.1, C29.1, C30.1, L2.2, R16.1, TP5.1; also elsewhere on the board
/VIN: C1.1, C2.1, C3.1, C4.1, C6.2, C7.1, C8.1, C9.1, C10.1, C14.1, C16.1, D1.1 (I/O), R8.1, R13.1, U1.4 (EN), U1.5 (VIN), U3.21 (PVIN), U3.22 (PVIN), U3.23 (PVIN), U3.24 (PVIN), U3.25 (PVIN); also elsewhere on the board
GND: C1.2, C2.2, C3.2, C4.2, C6.1, C7.2, C8.2, C9.2, C10.2, C11.2, C14.2, C16.2, C17.2, C18.2, C19.2, C20.2, C21.2, C25.2, C26.2, C27.2, C28.2, C29.2, C30.2, D1.2 (GND), J3.6, R12.2, R14.2, R15.2, TP6.1, U1.2 (GND), U2.2 (GND), U3.13 (PGND), U3.14 (PGND), U3.15 (PGND), U3.16 (PGND), U3.17 (PGND), U3.18 (PGND), U3.19 (PGND), U3.20 (PGND), U3.41 (PAD), U4.2 (GND); also elsewhere on the board
unnamed: C22.2, R14.1
unnamed: C12.2, U1.1 (CB)
unnamed: R11.2, R12.1, U1.3 (FB)
unnamed: C12.1, L1.1, U1.6 (SW)
unnamed: TP1.1, U3.31 (ADRSEL)
unnamed: C15.2, R13.2, U3.26 (AVIN)
unnamed: C23.1, U3.7 (BOOT)
unnamed: C5.1, R4.1, R5.1, U3.4 (BP1V5)
unnamed: C5.2, U3.5 (DRTN)
unnamed: C13.1, R8.2, R9.1, U3.27 (EN/UVLO)
unnamed: C24.2, R15.1, U3.34 (GOSNS)
unnamed: R5.2, R10.1, U3.32 (MSEL1)
unnamed: R6.2, U3.29 (MSEL2)
unnamed: C17.1, U3.28 (VDD5)
unnamed: C24.1, R16.2, U3.33 (VOSNS)
unnamed: R4.2, R7.1, U3.30 (VSEL)

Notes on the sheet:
1V8 LDO
Output 3.6V nominal 40A max
TPS546D24 is a Buck regulator that steps 12V down to 3.6V for the BM1366 chain
3V3 LDO
300 mA max
Remove R109, R110, R111 to isolate the PM Bus from the ESP32 master for configuration and debug.
Max 1.0A
Connect at U3 Pin 37
External PMBUS connector for TI GUI tool or I2C debug (Optional)
600 mA max
5V Supply
PGD is an open drain output from the TPS546D24. Pull up to 3.3V
I2C ADDR = 0x24

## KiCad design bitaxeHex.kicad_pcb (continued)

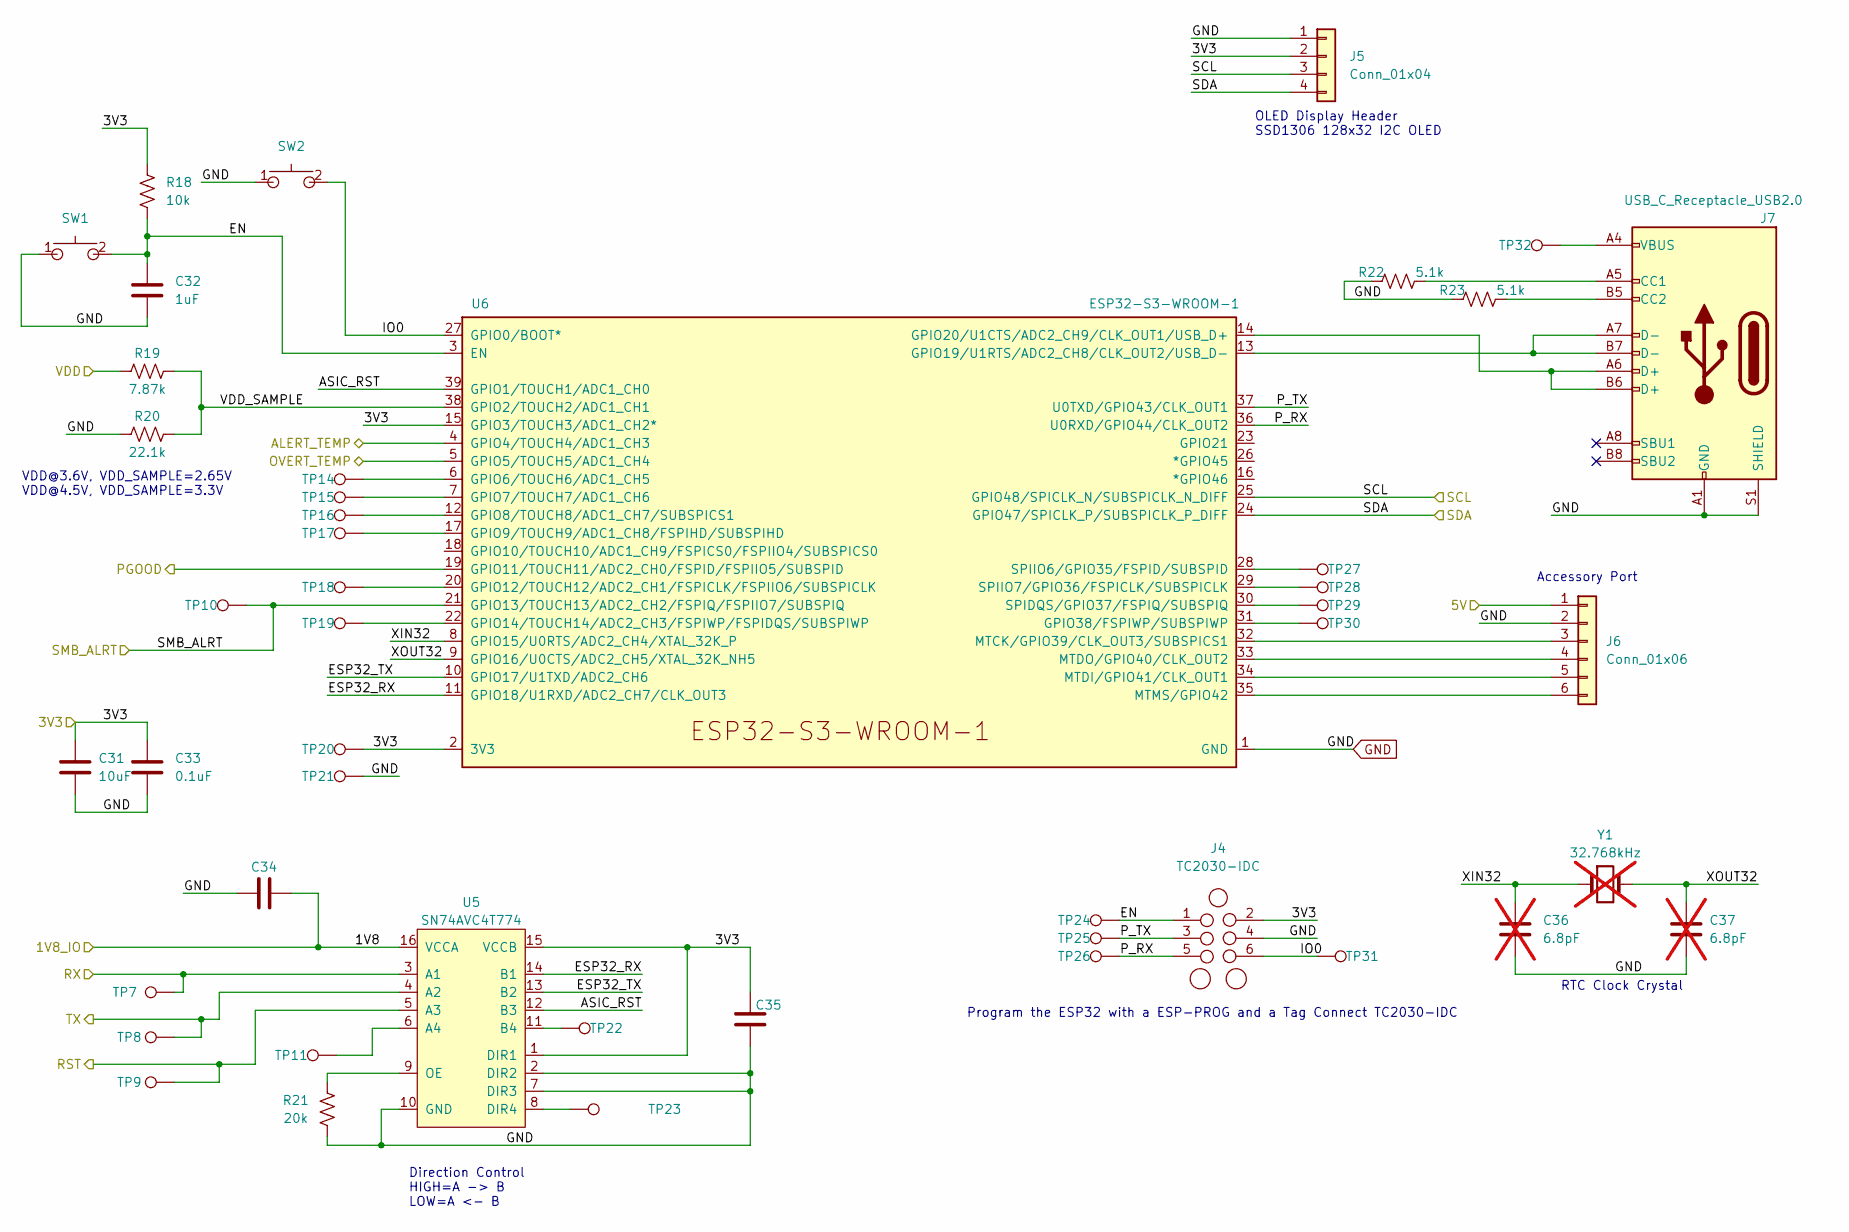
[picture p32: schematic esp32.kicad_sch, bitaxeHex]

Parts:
C31: 10uF; C_0805_2012Metric; PARTNO GRM21BR61H106ME43L
C32: 1uF; C_0402_1005Metric; PARTNO EMK105BJ105MV-F
C33: 0.1uF; C_0402_1005Metric; PARTNO KGM05AR71C104KH
C34, C35: 311-3342-1-ND; C_0402_1005Metric; PARTNO KGM05AR71C104KH
C36, C37: 6.8pF; C_0402_1005Metric; PARTNO C0402C689C5GAC7867; not fitted
J4: TC2030-IDC; Tag-Connect_TC2030-IDC-NL_2x03_P1.27mm_Vertical
J5: Conn_01x04; PinHeader_1x04_P2.54mm_Vertical
J6: Conn_01x06; PinHeader_1x06_P2.54mm_Vertical
J7: USB_C_Receptacle_USB2.0; USB_C_Receptacle_GCT_USB4105-xx-A_16P_TopMnt_Horizontal; PARTNO USB4105-GF-A
R18: 10k; R_0402_1005Metric; PARTNO RC0402JR-0710KL
R19: 7.87k; R_0402_1005Metric; PARTNO RC0402FR-077K87L
R20: 22.1k; R_0402_1005Metric; PARTNO RC0402FR-0722K1L
R21: 20k; R_0402_1005Metric; PARTNO RC0402FR-0720KL
R22, R23: 5.1k; R_0402_1005Metric; PARTNO RC0402FR-135K1L
SW1, SW2: SWITCH-SPST; TL3340-switch; PARTNO TL3340AF160QG
TP7, TP8, TP9, TP10, TP11, TP14, TP15, TP16, TP17, TP18, TP19, TP20, TP21, TP22, TP23, TP24, TP25, TP26, TP27, TP28, TP29, TP30, TP31, TP32: TestPoint; TestPoint_Pad_D1.0mm
U5: SN74AVC4T774; TSSOP-16_4.4x5mm_P0.65mm; PARTNO SN74AVC4T774PWR
U6: ESP32-S3-WROOM-1; ESP32-S3-WROOM-1U; PARTNO ESP32-S3-WROOM-1U-N16R8
Y1: 32.768kHz; SC32S-7PF20PPM; PARTNO SC32S-7PF20PPM; not fitted

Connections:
/3V3: C31.1, C33.1, C35.1, J4.2, J5.2, R18.1, TP20.1, U5.1 (DIR1), U5.15 (VCCB), U6.2 (3V3), U6.15 (GPIO3/TOUCH3/ADC1_CH2*); also elsewhere on the board
/5V: J6.1; also elsewhere on the board
/CI: TP8.1, U5.4 (A2); also elsewhere on the board
/ESP32/1V8: C34.2, U5.16 (VCCA)
/ESP32/ALERT_TEMP: U6.4 (GPIO4/TOUCH4/ADC1_CH3); also elsewhere on the board
/ESP32/ASIC_RST: U5.12 (B3), U6.39 (GPIO1/TOUCH1/ADC1_CH0)
/ESP32/EN: C32.1, J4.1, R18.2, SW1.2, TP24.1, U6.3 (EN)
/ESP32/ESP32_RX: U5.14 (B1), U6.11 (GPIO18/U1RXD/ADC2_CH7/CLK_OUT3)
/ESP32/ESP32_TX: U5.13 (B2), U6.10 (GPIO17/U1TXD/ADC2_CH6)
/ESP32/IO0: J4.6, SW2.2, TP31.1, U6.27 (GPIO0/BOOT*)
/ESP32/OVERT_TEMP: U6.5 (GPIO5/TOUCH5/ADC1_CH4); also elsewhere on the board
/ESP32/P_RX: J4.5, TP26.1, U6.36 (U0RXD/GPIO44/CLK_OUT2)
/ESP32/P_TX: J4.3, TP25.1, U6.37 (U0TXD/GPIO43/CLK_OUT1)
/ESP32/VDD_SAMPLE: R19.1, R20.2, U6.38 (GPIO2/TOUCH2/ADC1_CH1)
/ESP32/XIN32: C36.1, U6.8 (GPIO15/U0RTS/ADC2_CH4/XTAL_32K_P), Y1.1
/ESP32/XOUT32: C37.1, U6.9 (GPIO16/U0CTS/ADC2_CH5/XTAL_32K_NH5), Y1.2
/NRSTI: TP9.1, U5.5 (A3); also elsewhere on the board
/Power/PGOOD: U6.19 (GPIO11/TOUCH11/ADC2_CH0/FSPID/FSPIIO5/S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); also elsewhere on the board
/RO: TP7.1, U5.3 (A1); also elsewhere on the board
/SCL: J5.3, U6.25 (GPIO48/SPICLK_N/SUBSPICLK_N_DIFF); also elsewhere on the board
/SDA: J5.4, U6.24 (GPIO47/SPICLK_P/SUBSPICLK_P_DIFF); also elsewhere on the board
/SMB_ALRT: TP10.1, U6.21 (GPIO13/TOUCH13/ADC2_CH2/FSPIQ/FSPIIO7/S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); also elsewhere on the board
/VDD: R19.2; also elsewhere on the board
GND: C31.2, C32.2, C33.2, C34.1, C35.2, C36.2, C37.2, J4.4, J5.1, J6.2, J7.A1 (GND), J7.A12 (GND), J7.B1 (GND), J7.B12 (GND), J7.S1 (SHIELD), R20.1, R21.1, R22.1, R23.1, SW1.1, SW2.1, TP21.1, U5.2 (DIR2), U5.7 (DIR3), U5.10 (GND), U6.1 (GND), U6.40 (GND), U6.41 (GND); also elsewhere on the board
unnamed: J6.3, U6.32 (MTCK/GPIO39/CLK_OUT3/SUBSPICS1)
unnamed: J6.4, U6.33 (MTDO/GPIO40/CLK_OUT2)
unnamed: J6.5, U6.34 (MTDI/GPIO41/CLK_OUT1)
unnamed: J6.6, U6.35 (MTMS/GPIO42)
unnamed: J7.A5 (CC1), R22.2
unnamed: J7.B5 (CC2), R23.2
unnamed: J7.A4 (VBUS), J7.A9 (VBUS), J7.B4 (VBUS), J7.B9 (VBUS), TP32.1
unnamed: TP11.1, U5.6 (A4)
unnamed: TP22.1, U5.11 (B4)
unnamed: TP23.1, U5.8 (DIR4)
unnamed: R21.2, U5.9 (OE)
unnamed: TP14.1, U6.6 (GPIO6/TOUCH6/ADC1_CH5)
unnamed: TP15.1, U6.7 (GPIO7/TOUCH7/ADC1_CH6)
unnamed: TP16.1, U6.12 (GPIO8/TOUCH8/ADC1_CH7/SUBSPICS1)
unnamed: TP17.1, U6.17 (GPIO9/TOUCH9/ADC1_CH8/FSPIHD/SUBSPIHD)
unnamed: TP18.1, U6.20 (GPIO12/TOUCH12/ADC2_CH1/FSPICLK/FSPIIO6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)
unnamed: TP19.1, U6.22 (GPIO14/TOUCH14/ADC2_CH3/FSPIWP/FSPIDQS/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)
unnamed: J7.A7 (D-), J7.B7 (D-), U6.13 (GPIO19/U1RTS/ADC2_CH8/CLK_OUT2/USB_D-)
unnamed: J7.A6 (D+), J7.B6 (D+), U6.14 (GPIO20/U1CTS/ADC2_CH9/CLK_OUT1/USB_D+)
unnamed: TP30.1, U6.31 (GPIO38/FSPIWP/SUBSPIWP)
unnamed: TP29.1, U6.30 (SPIDQS/GPIO37/FSPIQ/SUBSPIQ)
unnamed: TP27.1, U6.28 (SPIIO6/GPIO35/FSPID/SUBSPID)
unnamed: TP28.1, U6.29 (SPIIO7/GPIO36/FSPICLK/SUBSPICLK)

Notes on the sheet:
OLED Display Header SSD1306 128x32 I2C OLED
RTC Clock Crystal
Accessory Port
Program the ESP32 with a ESP-PROG and a Tag Connect TC2030-IDC
VDD@3.6V, VDD_SAMPLE=2.65V VDD@4.5V, VDD_SAMPLE=3.3V
Direction Control HIGH=A -> B LOW=A <- B

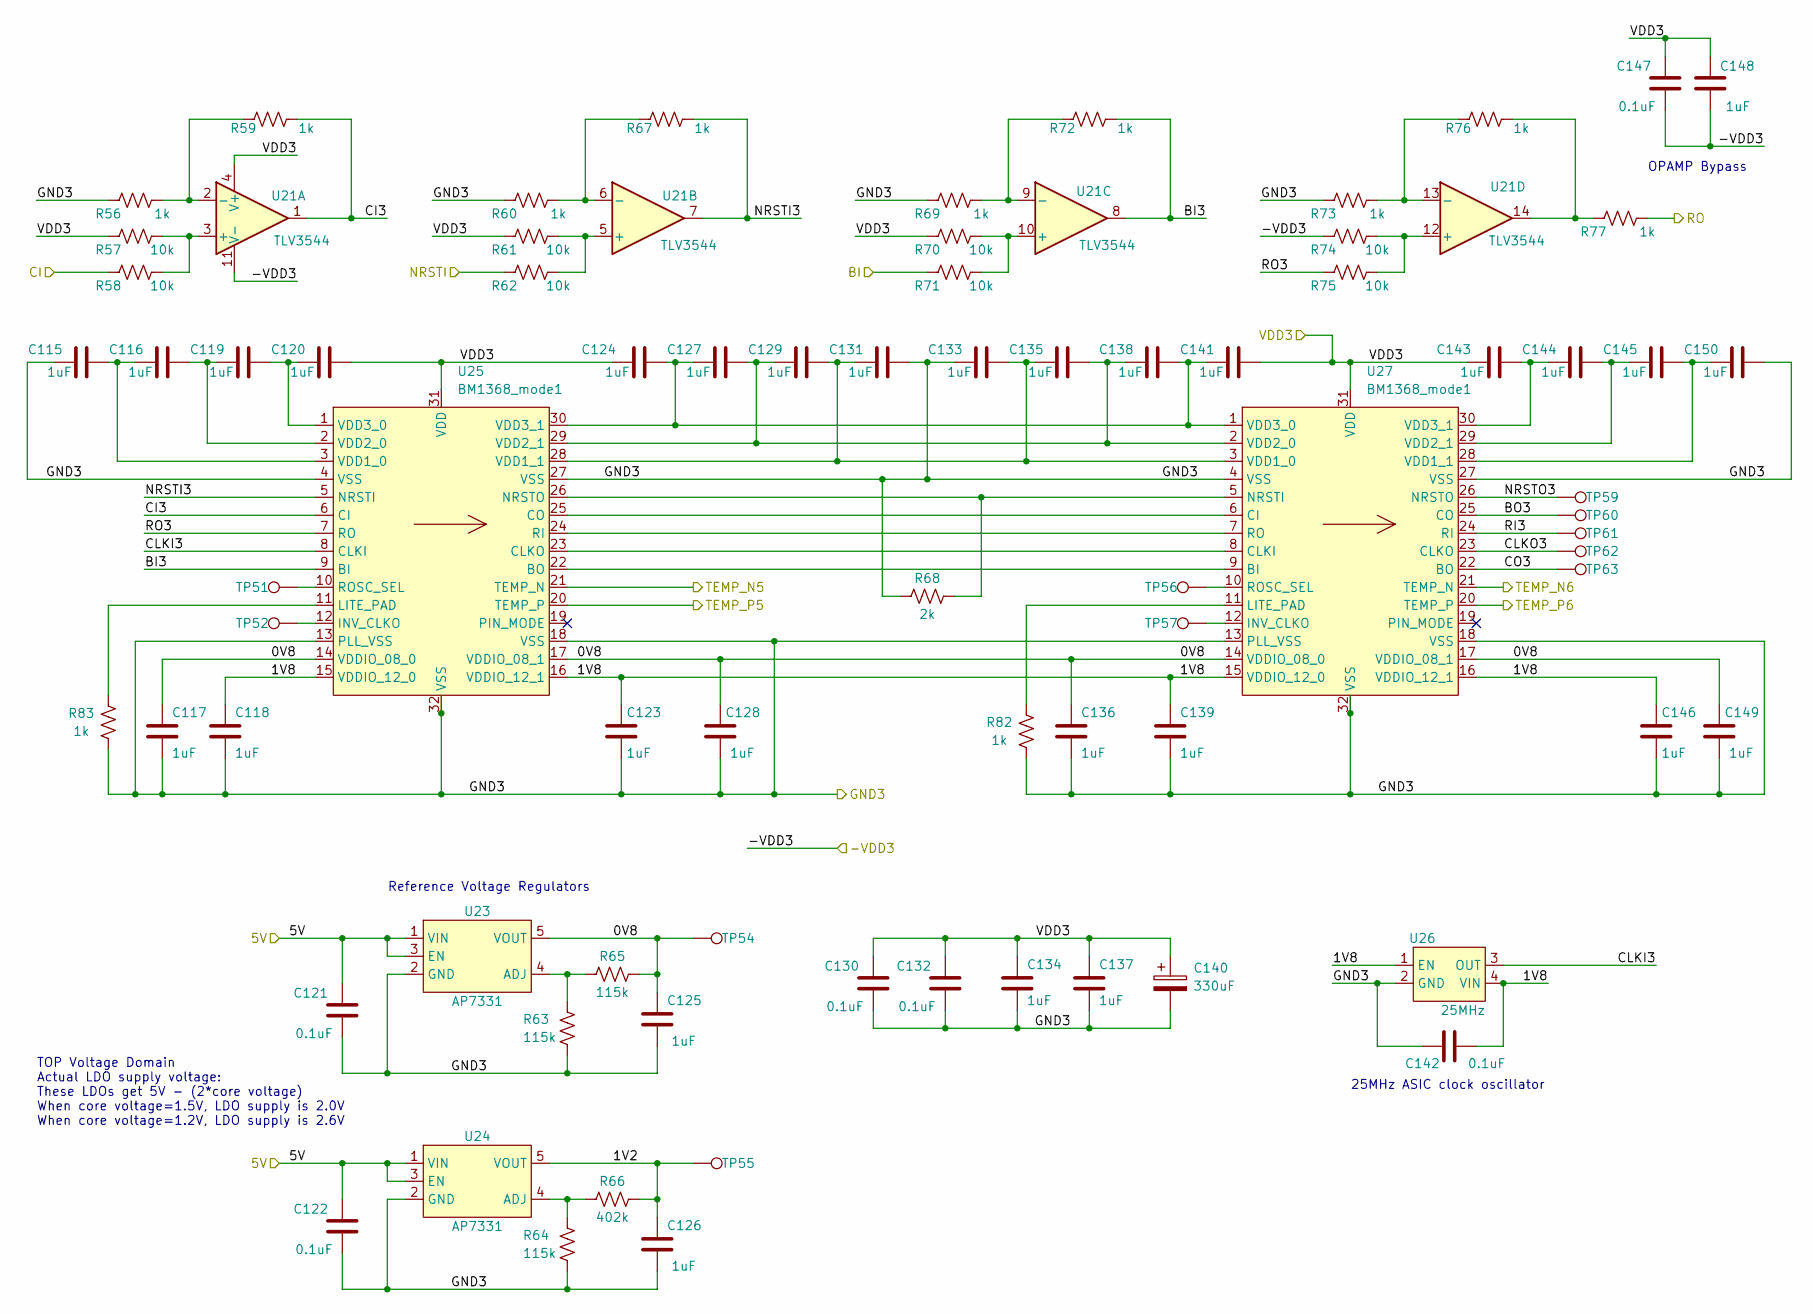
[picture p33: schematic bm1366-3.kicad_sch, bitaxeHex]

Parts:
C115, C116, C117, C118, C119, C120, C123, C124, C125, C126, C127, C128, C129, C131, C133, C134, C135, C136, C137, C138, C139, C141, C143, C144, C145, C146, C148, C149, C150: 1uF; C_0402_1005Metric; PARTNO EMK105BJ105MV-F
C121, C122, C130, C132, C142, C147: 0.1uF; C_0402_1005Metric; PARTNO KGM05AR71C104KH
C140: 330uF; CP_EIA-7343-31_Kemet-D_Pad2.25x2.55mm_HandSolder; PARTNO 293D337X9010E2TE3
R56, R59, R60, R67, R69, R72, R73, R76, R77, R82, R83: 1k; R_0402_1005Metric; PARTNO RC0402FR-071KL
R57, R58, R61, R62, R70, R71, R74, R75: 10k; R_0402_1005Metric; PARTNO RC0402JR-0710KL
R63, R64, R65: 115k; R_0402_1005Metric; PARTNO RC0402FR-07115KL
R66: 402k; R_0402_1005Metric; PARTNO RC0402FR-07402KL
R68: 2k; R_0402_1005Metric; PARTNO RT0402BRD072KL
TP51, TP52, TP54, TP55, TP56, TP57: TestPoint; TestPoint_Pad_D1.0mm
TP59, TP60, TP61, TP62, TP63: TestPoint; TestPoint_Pad_D1.5mm
U21: TLV3544; TSSOP-14_4.4x5mm_P0.65mm; PARTNO TLV3544IPWR
U23, U24: AP7331; TSOT-23-5; PARTNO AP7331-WG-7
U25, U27: BM1368_mode1; BM1368
U26: 25MHz; O 25,0-JO32-B-1V3-1-T1-LF; PARTNO O 25,0-JO32-B-1V3-1-T1-LF

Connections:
/5V: C121.2, C122.2, U23.1 (VIN), U23.3 (EN), U24.1 (VIN), U24.3 (EN); also elsewhere on the board
/BM1368-1/VDD1: C147.1, C148.1, R74.1, U21.11 (V-); also elsewhere on the board
/BM1368-2/BO: R71.1; also elsewhere on the board
/BM1368-2/CO: R58.1; also elsewhere on the board
/BM1368-2/NRSTO: R62.1; also elsewhere on the board
/BM1368-2/RI: R77.1; also elsewhere on the board
/BM1368-2/VDD2: C115.1, C117.2, C118.2, C121.1, C122.1, C123.2, C125.2, C126.2, C128.2, C130.1, C131.2, C132.1, C133.1, C134.2, C136.2, C137.2, C139.2, C140.2, C142.2, C146.2, C149.2, C150.2, R56.2, R60.2, R63.1, R64.1, R68.1, R69.2, R73.2, R82.1, R83.1, U23.2 (GND), U24.2 (GND), U25.4 (VSS), U25.13 (PLL_VSS), U25.18 (VSS), U25.27 (VSS), U25.32 (VSS), U26.2 (GND), U27.4 (VSS), U27.13 (PLL_VSS), U27.18 (VSS), U27.27 (VSS), U27.32 (VSS); also elsewhere on the board
/BM1368-3/0V8: C117.1, C125.1, C128.1, C136.1, C149.1, R65.2, TP54.1, U23.5 (VOUT), U25.14 (VDDIO_08_0), U25.17 (VDDIO_08_1), U27.14 (VDDIO_08_0), U27.17 (VDDIO_08_1)
/BM1368-3/BI3: R72.1, U21.8, U25.9 (BI)
/BM1368-3/BO3: TP60.1, U27.25 (CO)
/BM1368-3/CI3: R59.1, U21.1, U25.6 (CI)
/BM1368-3/CLKI3: U25.8 (CLKI), U26.3 (OUT)
/BM1368-3/CLKO3: TP62.1, U27.23 (CLKO)
/BM1368-3/CO3: TP63.1, U27.22 (BO)
/BM1368-3/NRSTI3: R67.1, U21.7, U25.5 (NRSTI)
/BM1368-3/NRSTO3: TP59.1, U27.26 (NRSTO)
/BM1368-3/RI3: TP61.1, U27.24 (RI)
/BM1368-3/RO3: R75.1, U25.7 (RO)
/BM1368-3/TEMP_N5: U25.21 (TEMP_N); also elsewhere on the board
/BM1368-3/TEMP_N6: U27.21 (TEMP_N); also elsewhere on the board
/BM1368-3/TEMP_P5: U25.20 (TEMP_P); also elsewhere on the board
/BM1368-3/TEMP_P6: U27.20 (TEMP_P); also elsewhere on the board
/VDD: C120.2, C124.1, C130.2, C132.2, C134.1, C137.1, C140.1, C141.2, C143.1, C147.2, C148.2, R57.1, R61.1, R70.1, U21.4 (V+), U25.31 (VDD), U27.31 (VDD); also elsewhere on the board
unnamed: R76.1, R77.2, U21.14
unnamed: R57.2, R58.2, U21.3 (+)
unnamed: R56.1, R59.2, U21.2 (-)
unnamed: R61.2, R62.2, U21.5 (+)
unnamed: R60.1, R67.2, U21.6 (-)
unnamed: R70.2, R71.2, U21.10 (+)
unnamed: R69.1, R72.2, U21.9 (-)
unnamed: R74.2, R75.2, U21.12 (+)
unnamed: R73.1, R76.2, U21.13 (-)
unnamed: R63.2, R65.1, U23.4 (ADJ)
unnamed: R64.2, R66.2, U24.4 (ADJ)
unnamed: U25.22 (BO), U27.9 (BI)
unnamed: U25.23 (CLKO), U27.8 (CLKI)
unnamed: U25.25 (CO), U27.6 (CI)
unnamed: TP52.1, U25.12 (INV_CLKO)
unnamed: R83.2, U25.11 (LITE_PAD)
unnamed: R68.2, U25.26 (NRSTO), U27.5 (NRSTI)
unnamed: U25.24 (RI), U27.7 (RO)
unnamed: TP51.1, U25.10 (ROSC_SEL)
unnamed: C115.2, C116.1, U25.3 (VDD1_0)
unnamed: C129.2, C131.1, C133.2, C135.1, U25.28 (VDD1_1), U27.3 (VDD1_0)
unnamed: C116.2, C119.1, U25.2 (VDD2_0)
unnamed: C127.2, C129.1, C135.2, C138.1, U25.29 (VDD2_1), U27.2 (VDD2_0)
unnamed: C119.2, C120.1, U25.1 (VDD3_0)
unnamed: C124.2, C127.1, C138.2, C141.1, U25.30 (VDD3_1), U27.1 (VDD3_0)
unnamed: TP57.1, U27.12 (INV_CLKO)
unnamed: R82.2, U27.11 (LITE_PAD)
unnamed: TP56.1, U27.10 (ROSC_SEL)
unnamed: C145.2, C150.1, U27.28 (VDD1_1)
unnamed: C144.2, C145.1, U27.29 (VDD2_1)
unnamed: C143.2, C144.1, U27.30 (VDD3_1)

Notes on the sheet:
25MHz ASIC clock oscillator
Reference Voltage Regulators
OPAMP Bypass
TOP Voltage Domain Actual LDO supply voltage: These LDOs get 5V - (2*core voltage) When core voltage=1.5V, LDO supply is 2.0V When core voltage=1.2V, LDO supply is 2.6V

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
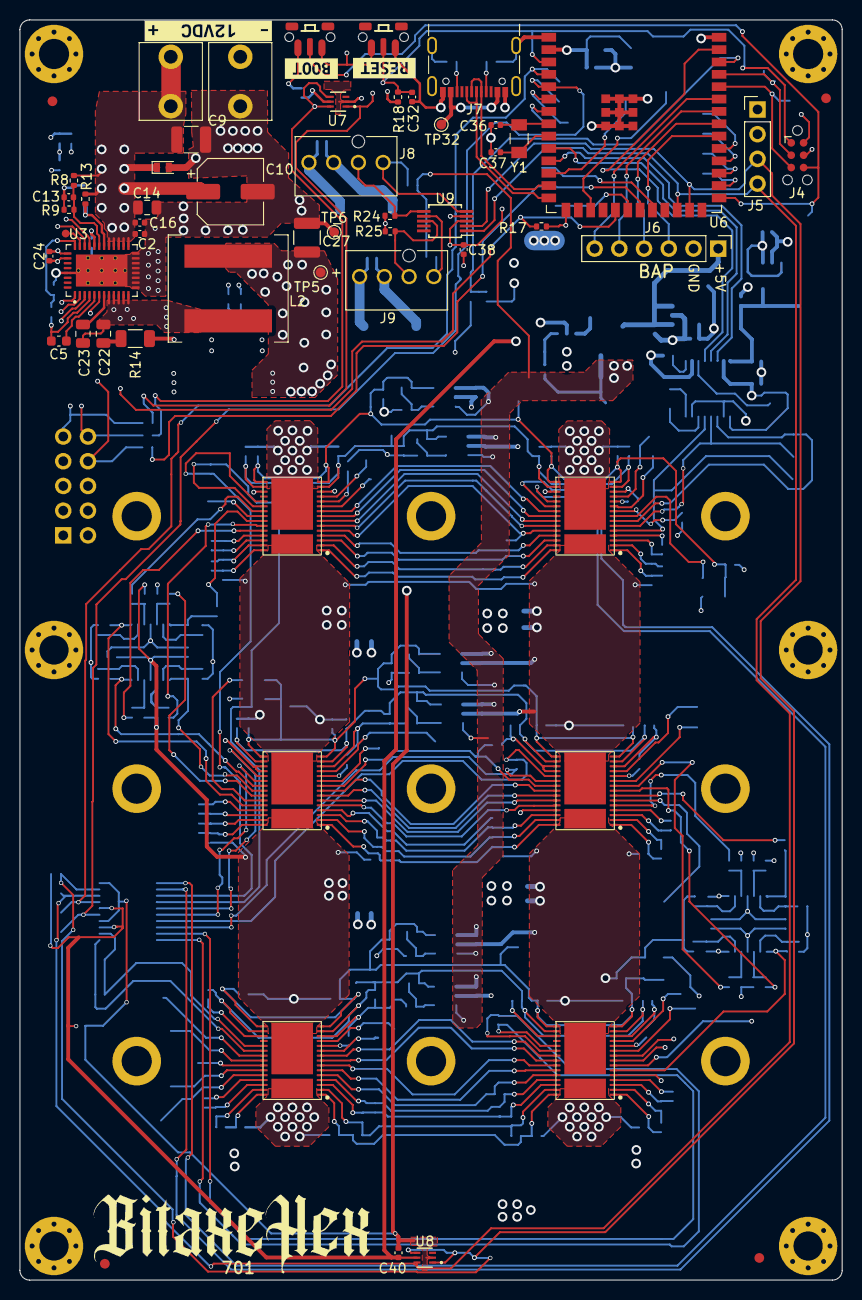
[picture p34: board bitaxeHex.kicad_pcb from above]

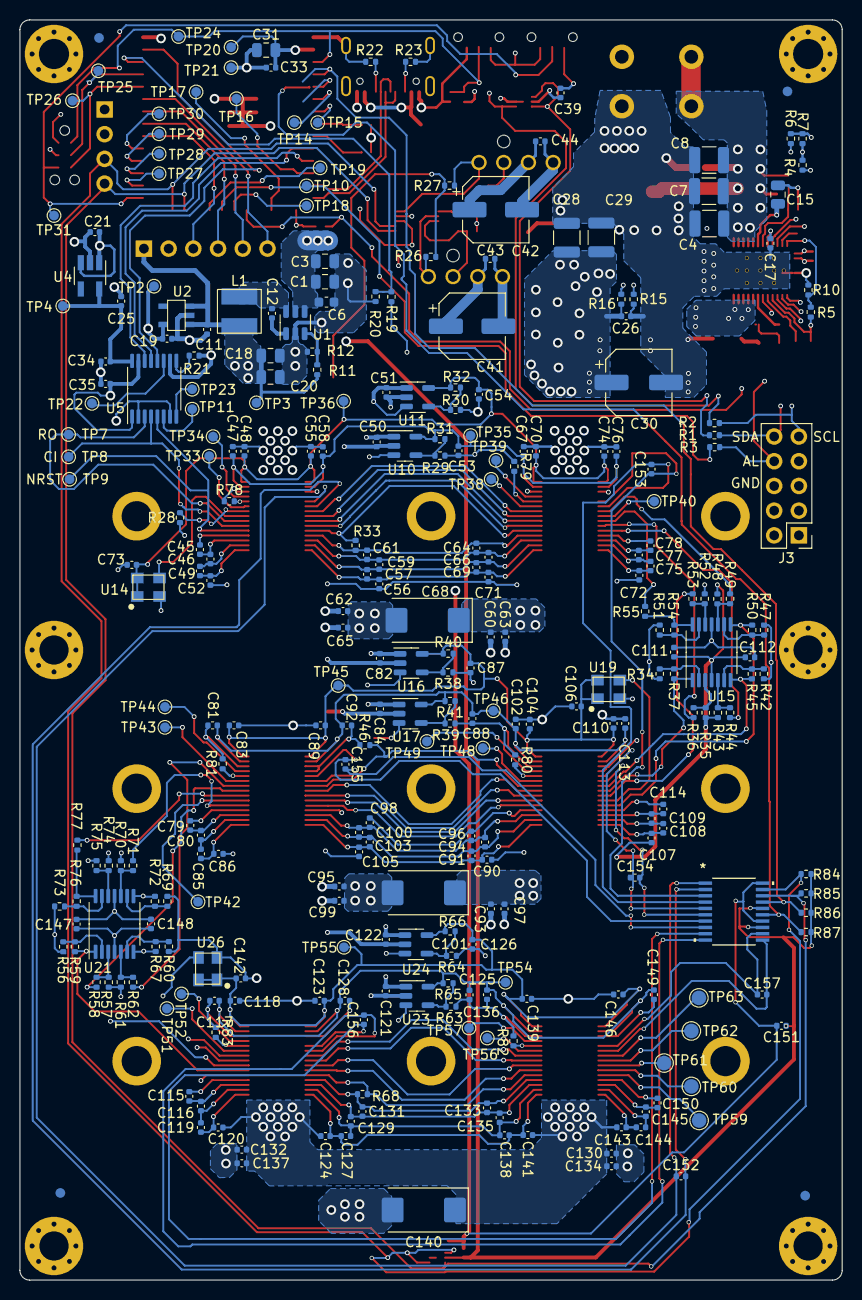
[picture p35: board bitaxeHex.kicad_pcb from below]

Board: 4 copper layers, 84.5 x 129.5 mm, 368 parts (293 on the bottom side), 205 nets.

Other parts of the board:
kibuzzard-65356D4E: G***; kibuzzard-65356D4E
kibuzzard-65356D5C: G***; kibuzzard-65356D5C
kibuzzard-65978662: G***; kibuzzard-65978662

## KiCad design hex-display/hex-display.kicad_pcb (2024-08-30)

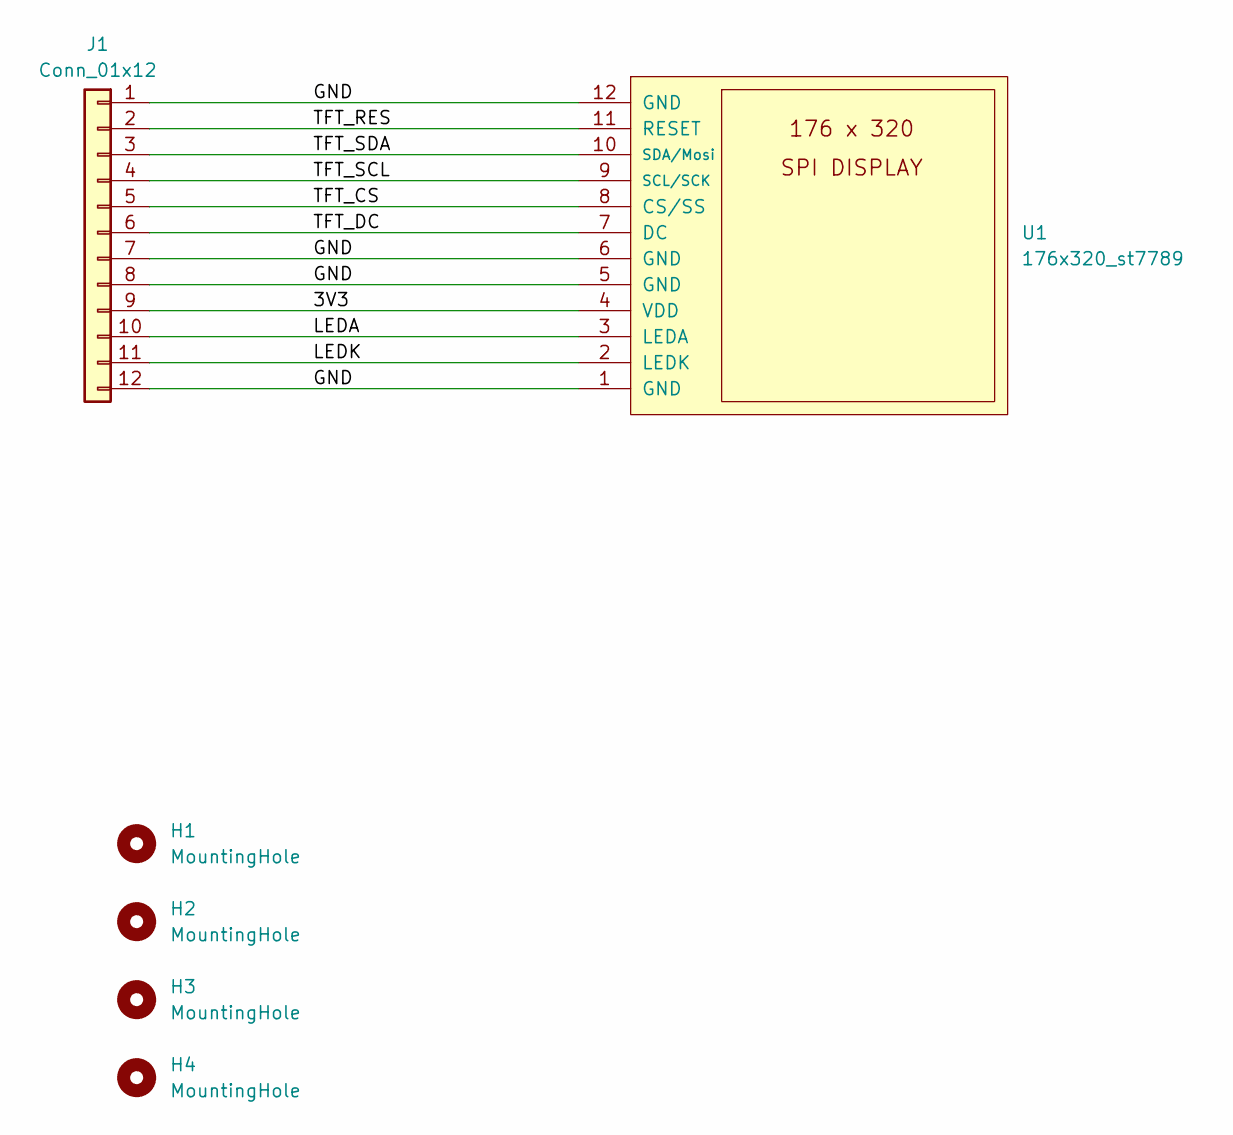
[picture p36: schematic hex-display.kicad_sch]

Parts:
H1, H2, H3, H4: MountingHole; 4mm_mounting
J1: Conn_01x12; JST_GH_BM12B-GHS-TBT_1x12-1MP_P1.25mm_Vertical
U1: 176x320_st7789; ST7789-176x320

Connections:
/3V3: J1.9, U1.4 (VDD)
/GND: J1.1, J1.7, J1.8, J1.12, U1.1 (GND), U1.5 (GND), U1.6 (GND), U1.12 (GND)
/LEDA: J1.10, U1.3 (LEDA)
/LEDK: J1.11, U1.2 (LEDK)
/TFT_CS: J1.5, U1.8 (CS/SS)
/TFT_DC: J1.6, U1.7 (DC)
/TFT_RES: J1.2, U1.11 (RESET)
/TFT_SCL: J1.4, U1.9 (SCL/SCK)
/TFT_SDA: J1.3, U1.10 (SDA/Mosi)

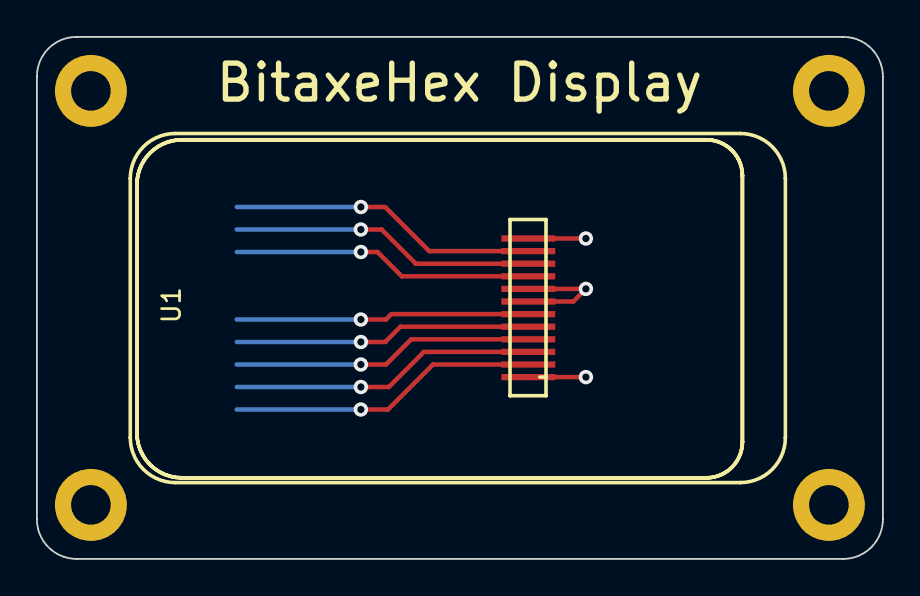
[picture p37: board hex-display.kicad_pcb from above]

Board: 2 copper layers, 47.0 x 29.0 mm, 6 parts (1 on the bottom side), 9 nets.

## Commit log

2024-08-30 init 701
    [21-0066J_20_MXM.step, 21-0164B_L622-1_MXM.step, 2R5TPE220MAFB.step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]
2024-08-30 update gerber
    [bitaxeHex-B_Cu.gbr, bitaxeHex-B_Mask.gbr, bitaxeHex-B_Paste.gbr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]
2024-09-09 -Reset to 1V8/0V8 setup -Add TVS protection
    [Download_STP_WE-TVS-DFN1610-2L_rev1.stp, Temp_Monitoring.kicad_sch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]
2025-03-17 updated to KiCad v9, filled in incomplete BOM and exported.
    [Temp_Monitoring.kicad_sch, bitaxeHex.kicad_pcb, bitaxeHex.kicad_sch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]
2025-03-17 change the gitignore to actually add the BOM
    [bitaxeHex BOM.csv]

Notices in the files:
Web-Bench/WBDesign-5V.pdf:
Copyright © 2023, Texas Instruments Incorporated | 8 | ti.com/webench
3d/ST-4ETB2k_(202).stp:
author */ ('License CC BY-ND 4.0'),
